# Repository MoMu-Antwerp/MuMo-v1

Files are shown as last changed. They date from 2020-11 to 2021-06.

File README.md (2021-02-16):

# MuMo
The MuMo project is an attempt to make an open source easy to setup platform to monitor environmental conditions of multiple sensors using IOT Lora modules and off the shelf hardware. 

MuMo stands for 'Museum Monitoring' and refers to the initial founder and prototype developer of the project, which is the fashion museum in Antwerp (named MoMu). MuMo is developed in collaboration with the University of Antwerp - Department of Product Development. 

The project consists of 3 main parts. A sensor node design, a gateway that also houses various sensors and a dashboard to visualize all recorded measurements and to alert users of any out of bound values. 

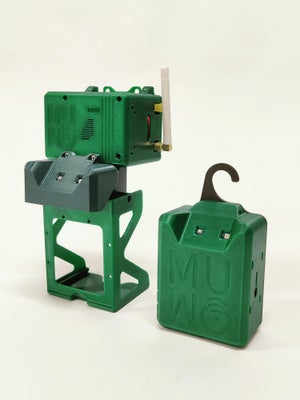
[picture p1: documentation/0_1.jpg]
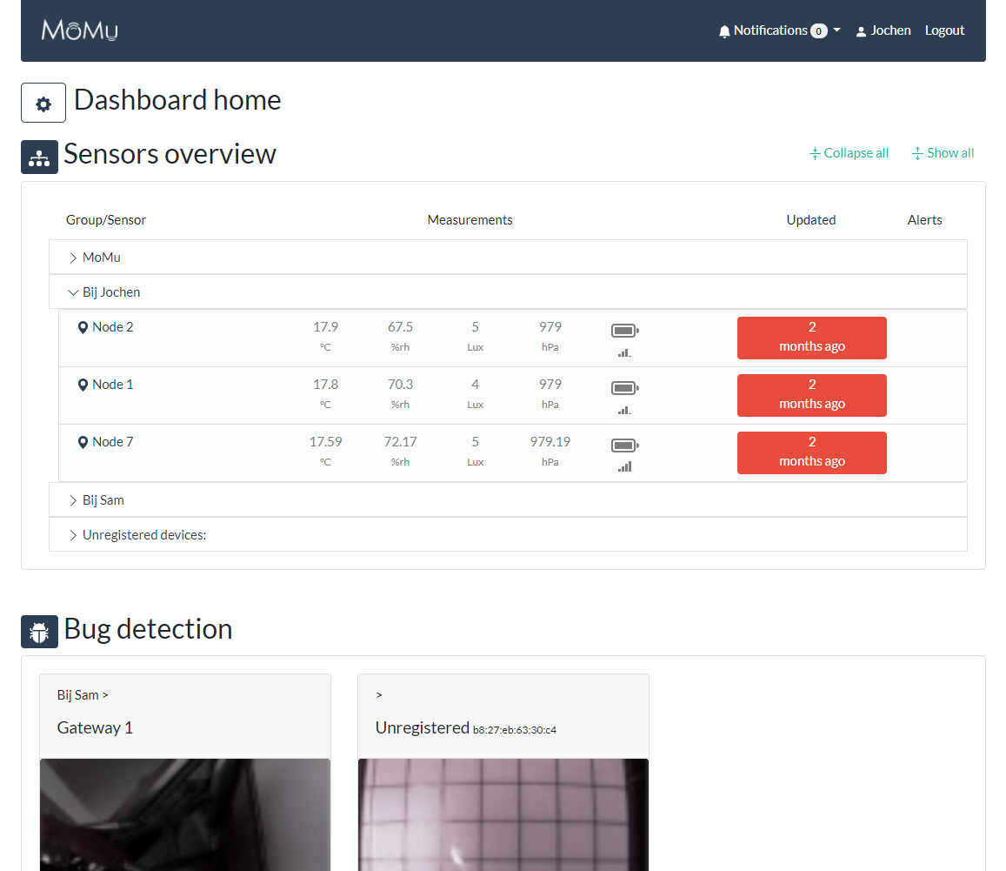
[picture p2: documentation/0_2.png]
 

### The sensor node 

The sensor node is built around a Lorawan Seeed board that contains a ATSAMD21 processor (arduino zero compatible) and a RHF76 Lora module. 

It features Seeed grove sensor connectors that can accommodate a series of sensors. In this project we chose a BME680 that records environment temperature, relative humidity and barometric pressure and a TSL2561 to measure visible light values (in lux). 

To power the unit for a long period of time, we use 6 rechargeable AA batteries that should give the node an operating cycle of around two years (depending on the frequency of measurements sent). 

All in a 3D printer optimized housing and programmable without special tools. 

The code features: 

- The Things Network connection 
- Measurement frequency from minutes to days 
- Intermittent measurements every minute to check for extreme conditions. 
- Immediate warning transmissions if any warnings are raised. 
- Down-linkable updates to all settings 
- Ability to connect other sensors by adding their library and implementation. 
- Decent power efficiency by using the internal RTC of the ATSAMD21 (down to 65 µA) 

### The Gateway 

Build around a Raspberry Pi and containing a Dragino lora concentrator, dust particle sensor, Grove sensor shield with environmental sensors connected and a bug detection camera. Most of these components are modular and optional, so that any useful combination of elements can be made. 

The inclusion of the Dragino Lora concentrator makes this unit a Lora gateway that receives all data from the nodes and forwards the data to the things network through a WIFI connection or Ethernet. Using this board hundreds of nodes can be connected. 

Python code on the Pi records all measurements like is done on the Nodes themselves. But in this case also utilizes the power consuming VOC measurements of the BME680 and an extra dust particle sensor (also power consuming that would not be desirable in the battery powered nodes). 

A night vision camera can be placed in various locations around the unit to record bug traps. It provides a daily updated picture that can give a history log of events that occurred.  

This unit also features a 3D printer optimized housing and is programmable without specialist tools. 

#### Ready made alternative Gateway (TTN indoor gateway)
If you are just interested in the functionalities of the sensor nodes and dashboard, there is an easier alternative Gateway solution. You can order a The Things Indoor Gateway and activate this ready-made gateway in less that 5 minutes. You can find more information [on the site of TTN](https://www.thethingsnetwork.org/docs/gateways/thethingsindoor/index.html).

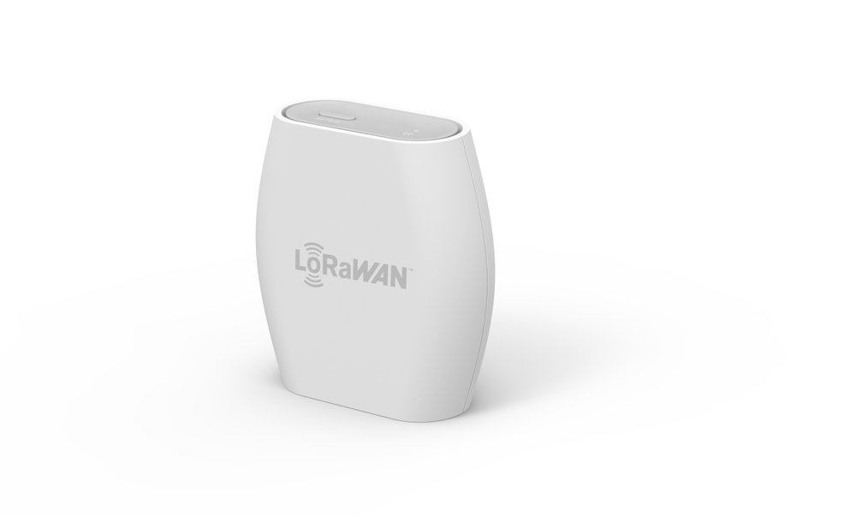
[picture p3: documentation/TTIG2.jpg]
 

### The Dashboard 

The dashboard visualizes the data received by The Things Network. It shows the latest measurements captured by the sensors from the nodes and gateway in one application. And shows graph of all recorded measurements up to date. It gives a manageable overview to setup alerts for any out of bound recordings and can be integrated in other platforms (if desired). On top of this, the calibration of the sensors and user access is managed with this dashboard. 

Requirements: 

- PHP version 5.6 or greater. 
- MYSQL version 5.6 or greater or MariaDB version 10.1 or greater. 
- Online accessible url (may be a subdomain as well) 

## Open source 

All the development done for this project is open to be used, modified and shared if credits are given.  

In this github you can find:  
- Shopping lists for all parts that we used. 
- .Stl files to print any of the housings. 
- Codes for the nodes, gateways and dashboard. 
- Manuals to take you through the assembly step by step. 

# Where to find all parts:
- [Shopping list for the project.](/Shopping_list.md)
---
### Node
- [Step by step assembly manual of the Node.](/Node/readme.md)
- [STL files to 3D print the Node housing.](/Node/STL_NODE)
- [Latest Arduino code of the Node.](/Node/mumoV1)
---
### Gateway / extensions
- [Step by step assembly manual of the Gateway.](/Gateway/readme.md)
- [STL files to 3D print the Gateway housing / extensions.](/Gateway/STL_GATEWAY)
---
### Dashboard
- [Step by step installation of the online dashboard.](/Dashboard/readme.md)
- [All required files can be found in the same folder.](/Dashboard)

# Contributions

The MuMo project is a collaboration between [MoMu](https://www.momu.be/en/) and the [University of Antwerp](https://www.uantwerpen.be/nl/studeren/aanbod/alle-opleidingen/productontwikkeling-studeren/) - [Antwerp design factory](https://www.uantwerpen.be/nl/projecten/mondmaskers/over-ons/antwerp-design-factory/).

Funded by the Flemish Government [Innovatief  partnerproject](https://www.vlaanderen.be/cjm/nl/cultuur/cultuur-en-economie/innovatieve-partnerprojecten) under the name: Developing a IOT Datalogger for Museums using LoRaWan

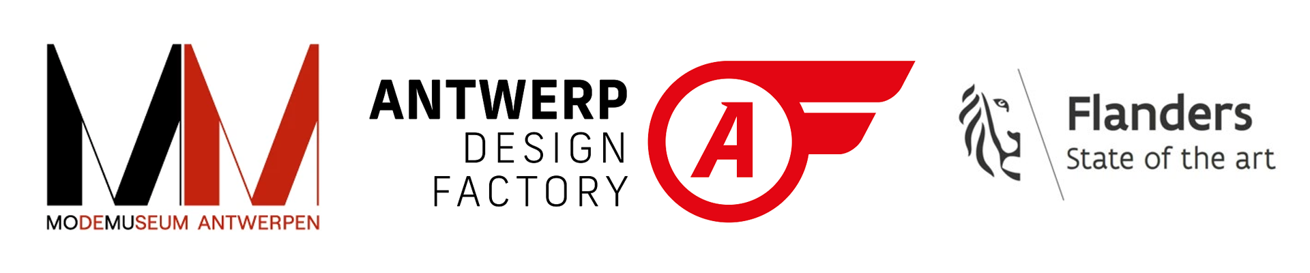
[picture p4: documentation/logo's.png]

---

Shield: [][cc-by-sa]

This work is licensed under a
[Creative Commons Attribution-ShareAlike 4.0 International License][cc-by-sa].

[][cc-by-sa]

[cc-by-sa]: http://creativecommons.org/licenses/by-sa/4.0/
[cc-by-sa-image]: https://licensebuttons.net/l/by-sa/4.0/88x31.png
[cc-by-sa-shield]: https://img.shields.io/badge/License-CC%20BY--SA%204.0-lightgrey.svg

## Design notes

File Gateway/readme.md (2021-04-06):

# MuMo Gateway setup
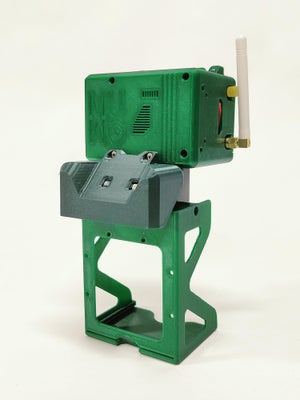
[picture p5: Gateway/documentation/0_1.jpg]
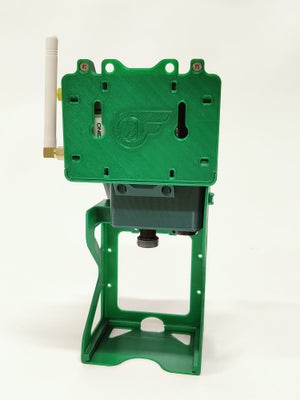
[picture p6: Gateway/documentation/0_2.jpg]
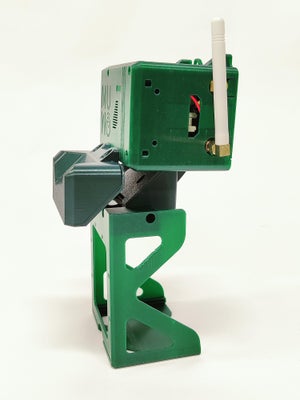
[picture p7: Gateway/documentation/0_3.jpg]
   

### Required Tools:
- 3D printer with filament
- Solder iron / solder
- Small cutting plier
- Hot glue gun (or other fixation tools)
- Small screwdriver

## Step 1: #Hardware - Ordering Parts
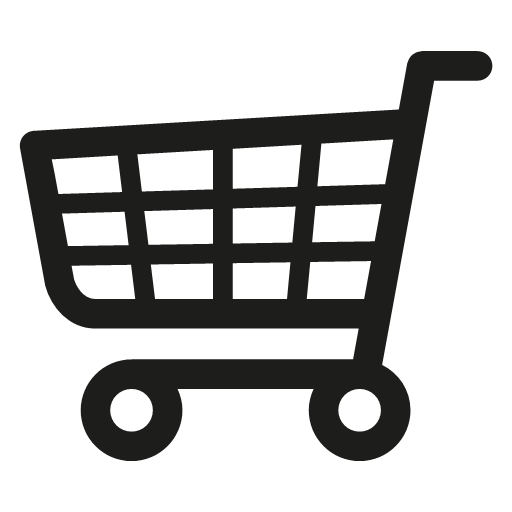
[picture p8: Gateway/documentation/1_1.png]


See the shopping list an up-to-date overview:
- [Shopping list for the project.](/Shopping_list.md)

In the construction of the gateway you have a few options in the features you like to add:
- Either an active or passive gateway (with or without sensors on the gateway).
- Lora gateway or just an active sensor (with or without lorawan concentrator shield).
- With or without camera module for bug tracking or other camera applications.

> In the instructions below we describe the most commong optional parts (without camera and without sensors). 
> But note that you can easily leave out the lorawan concentrator as well if you already have gateways on site.

***Be carefull*** about the screws nearby the Raspberry Pi. Don't overtighten the screws and if you notice it being to close to the electronics we advice you to shim the parts a bit or to use a smaller screw.

## Step 2: #Hardware - 3D Printed Parts
Check the github page for the latest STL files:
[Gateway STL files](/Gateway/STL_GATEWAY)
- ***1x*** GATEWAY_Main_Housing
- ***1x*** GATEWAY_Backcover
- ***1x*** Sensor_extension
- ***1x*** Sensor_Housing
- ***1x*** Sensor_Backcover
- ***1x*** Camera_Housing
- ***1x*** Camera_Backcover

### Material and print settings:
- ***PETG*** preffered (for durability against the heat of the gateway)
- No supports needed
- Infill not necessary
- 0.2 layer height
- 3 outside perimeters (for strength and durability)

## Step 3: #Software - Prepare SD Card Raspberry Pi
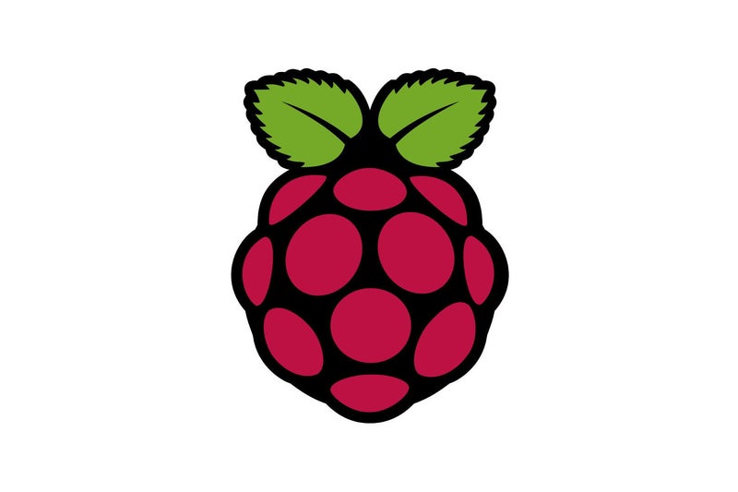
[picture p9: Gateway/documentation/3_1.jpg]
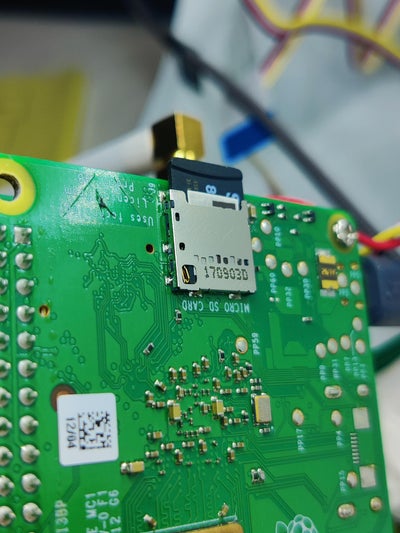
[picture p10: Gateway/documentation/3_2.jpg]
 

### Parts:

- ***1x*** Raspberry Pi
- ***1x*** Micro SD card.

### Instructions:

1. Make sure the SD card is flashed with the Raspberry Pi operation system (Raspberry Pi OS(32-bit) with desktop). 
1. Insert your micro SD card into the Raspberry Pi.

> Follow the link below to find more detailed instructions how to flash and prepare your micro SD card. [Raspberry installation instructions](https://www.raspberrypi.org/documentation/installation/installing-images/)

## Step 4: #Hardware - Prepare the Air Dust Sensor (optional)

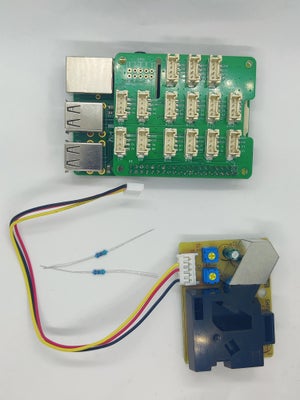
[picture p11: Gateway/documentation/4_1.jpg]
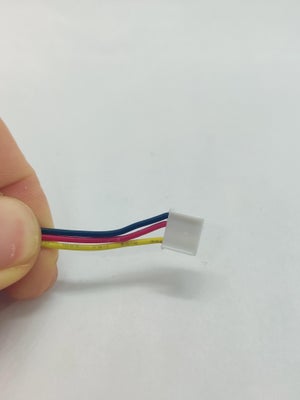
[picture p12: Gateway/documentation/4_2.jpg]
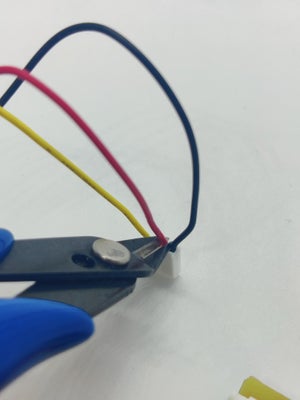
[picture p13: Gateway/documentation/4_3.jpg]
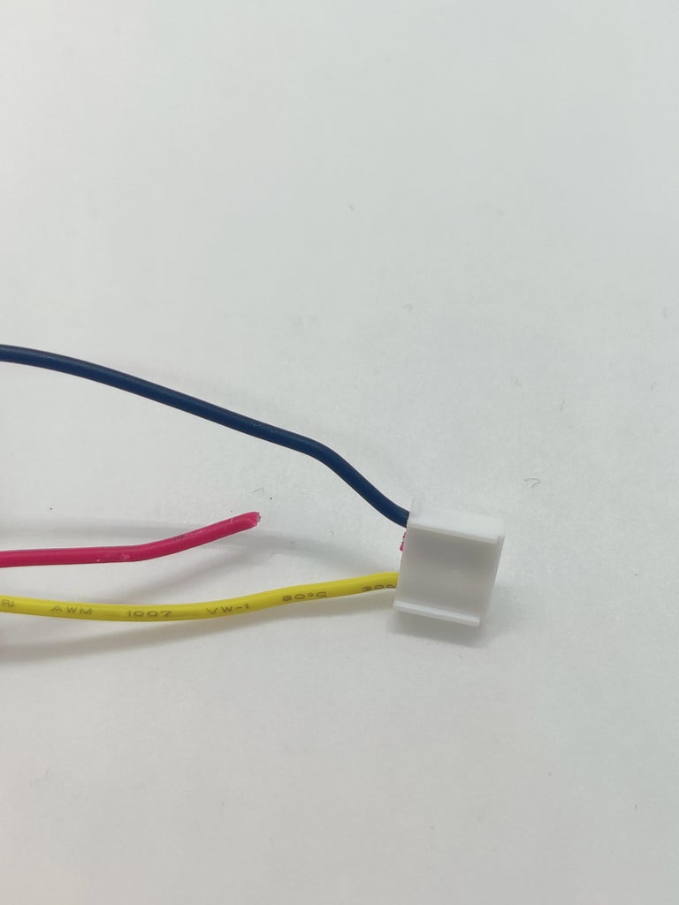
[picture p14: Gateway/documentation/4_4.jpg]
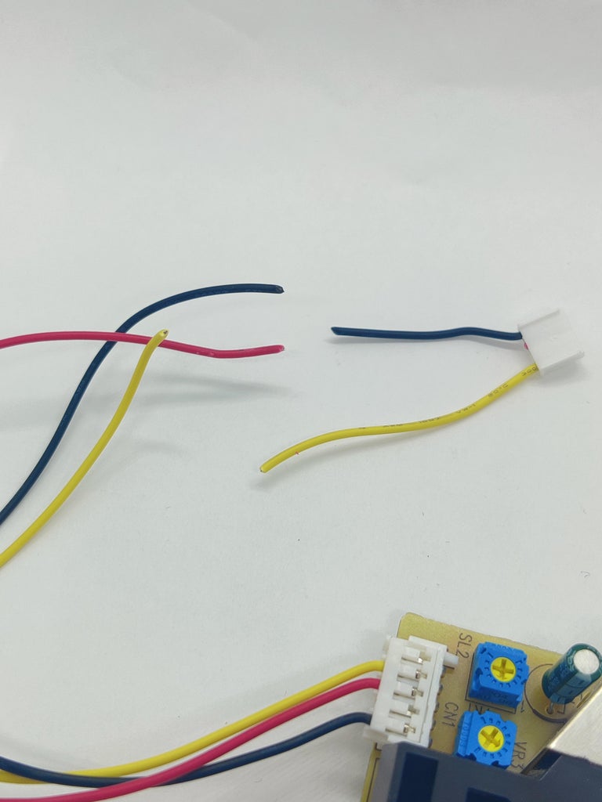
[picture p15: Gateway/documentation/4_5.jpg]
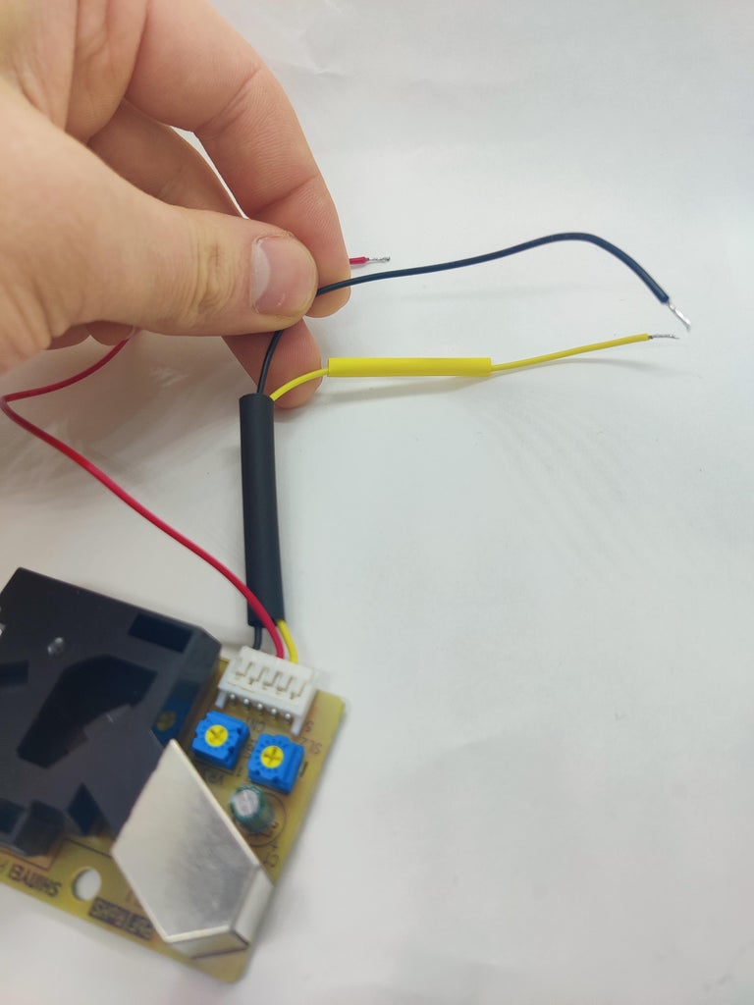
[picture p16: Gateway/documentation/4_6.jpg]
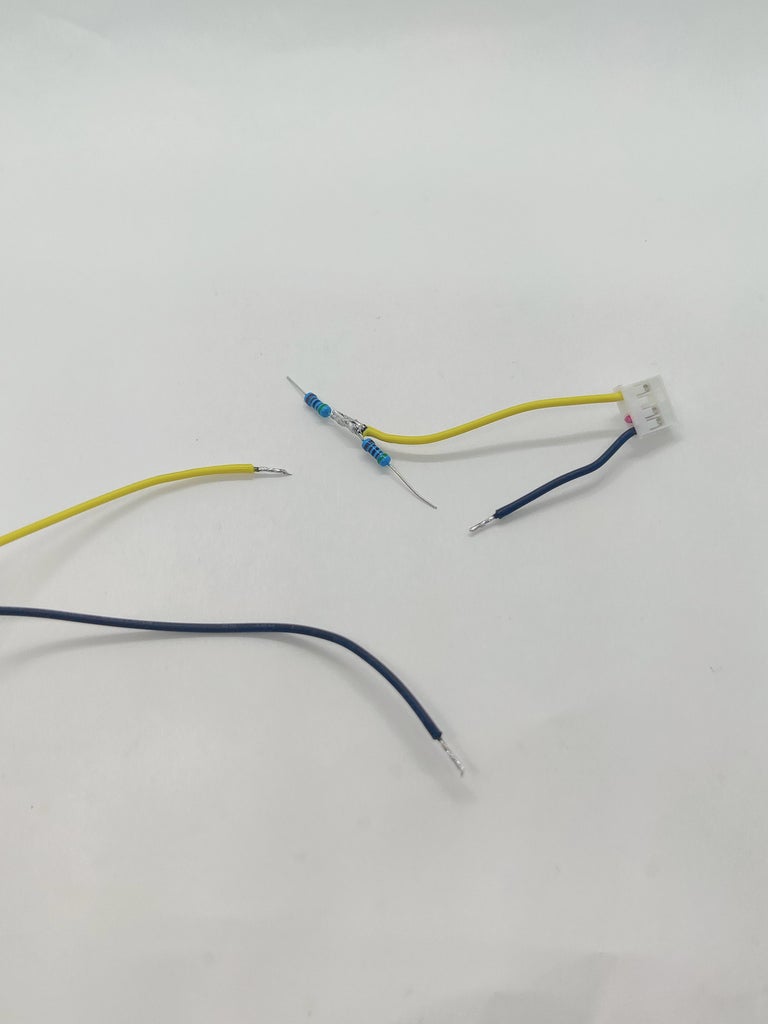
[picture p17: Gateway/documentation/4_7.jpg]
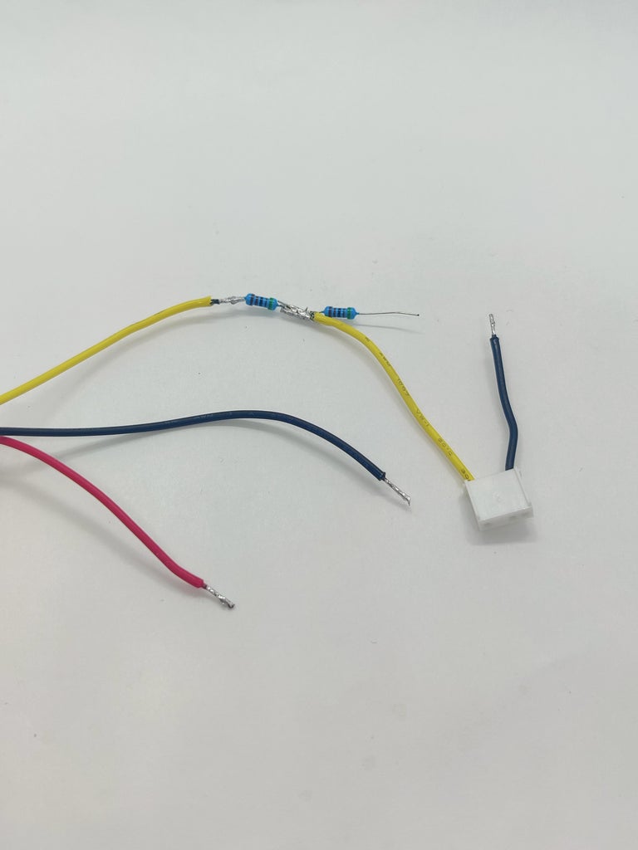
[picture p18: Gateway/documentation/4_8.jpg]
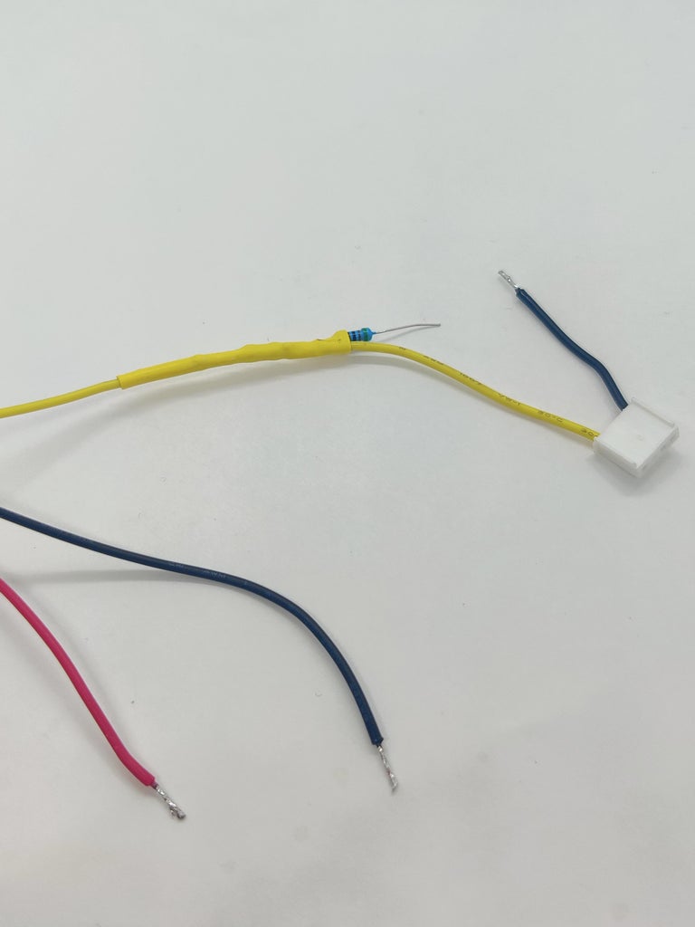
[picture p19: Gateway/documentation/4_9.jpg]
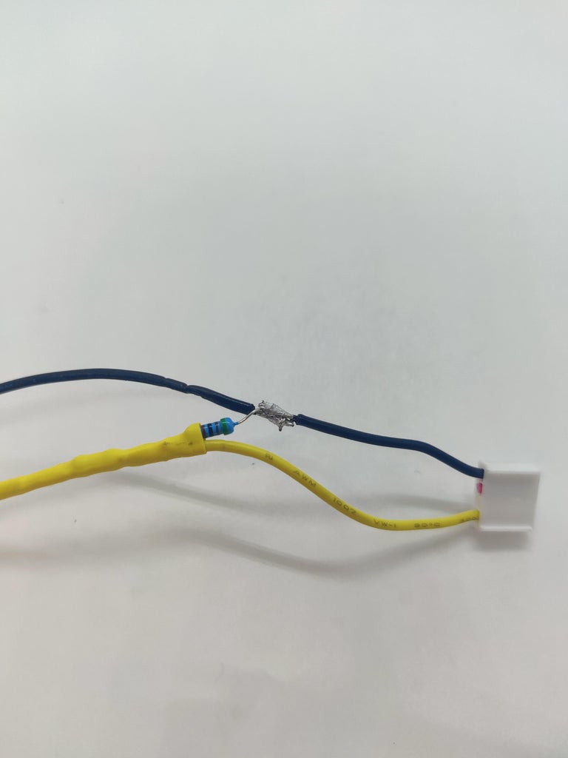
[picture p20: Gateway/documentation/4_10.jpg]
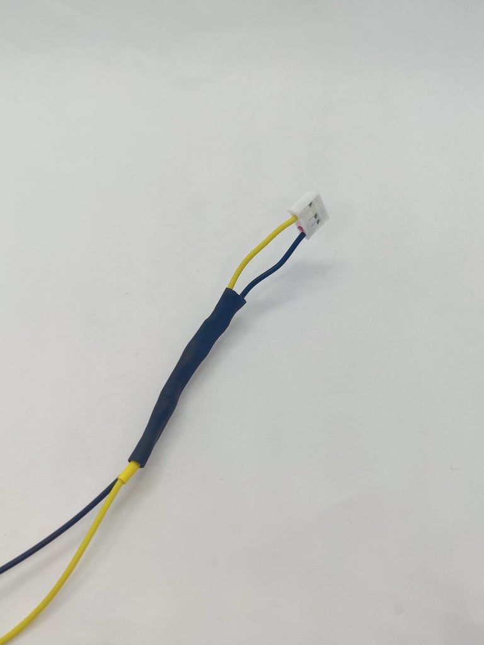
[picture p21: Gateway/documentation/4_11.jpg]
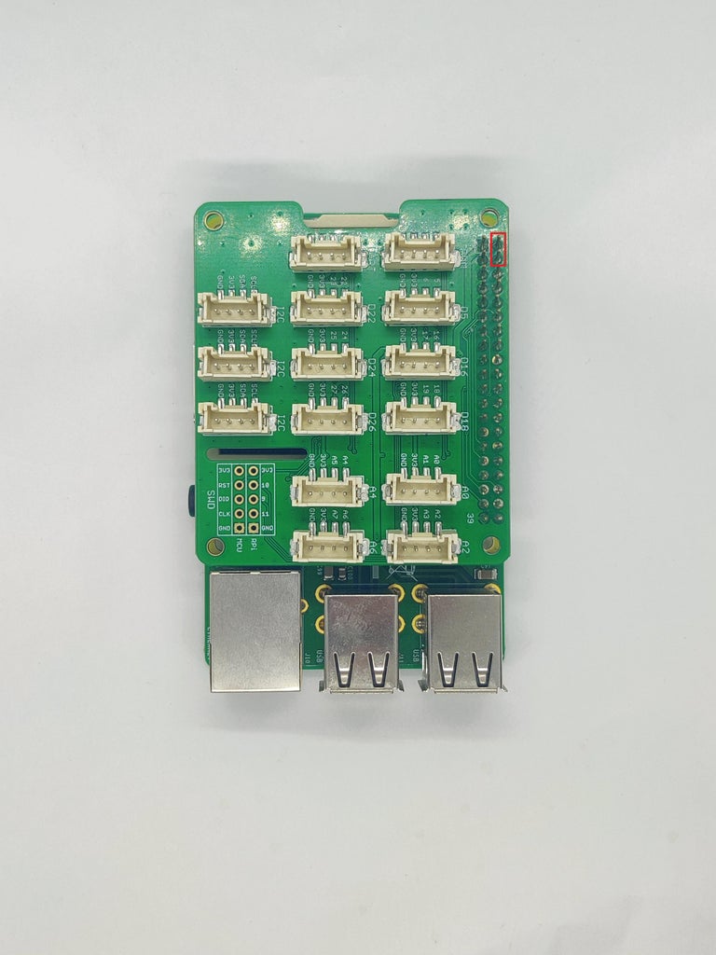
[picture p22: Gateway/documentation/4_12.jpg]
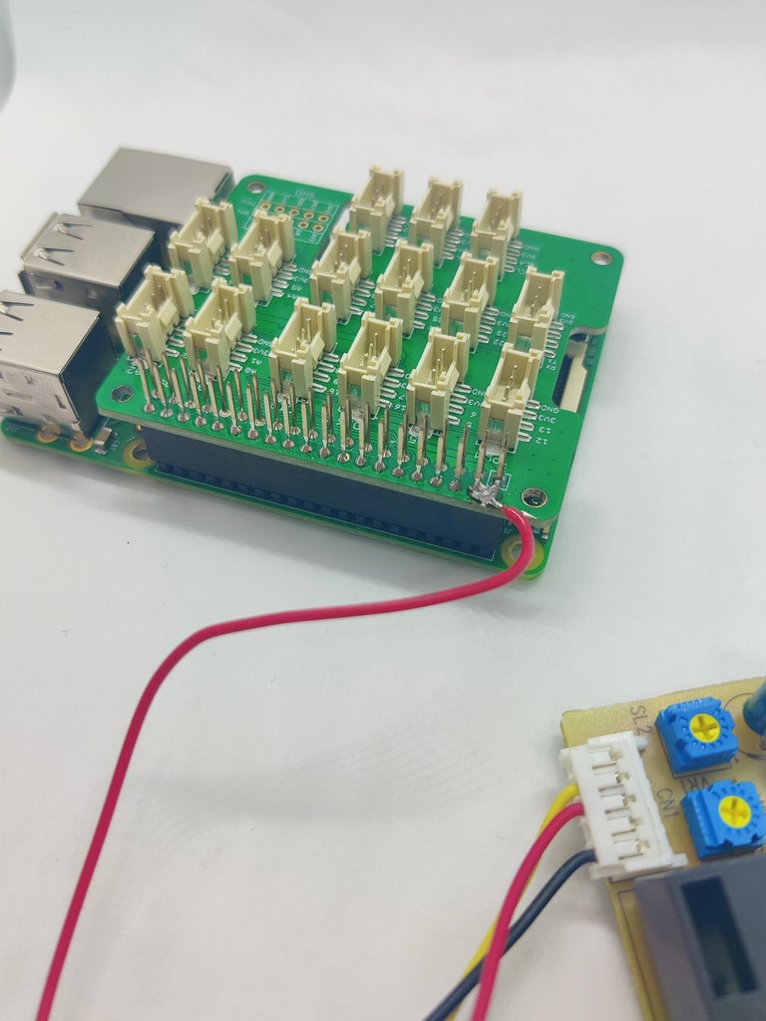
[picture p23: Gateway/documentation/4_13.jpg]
             

Since the air dust sensor works on 5V supply and the raspberry pi only works on 3.3V we need to include a voltage devider in the cable using two resistors.

### Parts:

- ***1x*** Seeed air dust sensor
- ***2x*** resistor (3.3 KΩ) (orange, orange, red)
- ***1x*** Grove hat
- ***2x*** shrink sleeves

### Instructions:
1. Cut the red wire up to the connector.
1. Cut the yellow wire at a distance of 3 cm from the connector.
1. Cut the black wire at a distance of 2 cm from the connector.
1. Strip the end of each wire.
1. Put a small shrink sleeve over the yellow cable.
1. Put a large shrink sleeve over the yellow and black cable.
1. Solder the two resistors in series with the yellow cable of the connector in between.
1. Solder the other yellow cable on the side of the sensor to one of the resistors.
1. Slide the small sleeve over the solder connection of the yellow wire with one resistor end still exposed and heat shrink the small sleeve.
1. Solder the black wires back together with the still exposed resistor leads in between.
1. Slide the large sleeve over the solder connection and the small sleeve and heat shrink the large sleeve.
1. Solder the red cable to the 5V pins (pin 2 and 4) on the Grove hat board (see the top view picture).

## Step 5: #Hardware - Mounting the Spacers (optional)
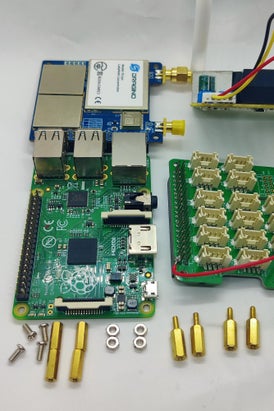
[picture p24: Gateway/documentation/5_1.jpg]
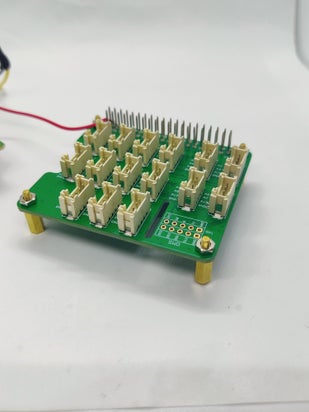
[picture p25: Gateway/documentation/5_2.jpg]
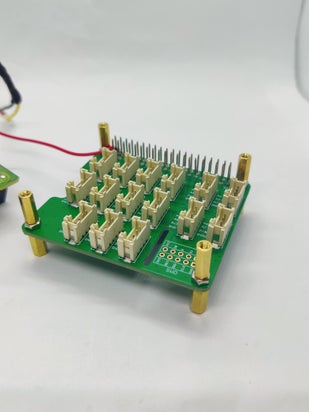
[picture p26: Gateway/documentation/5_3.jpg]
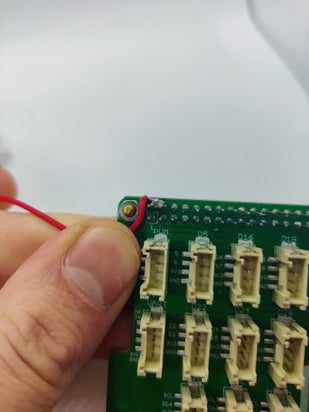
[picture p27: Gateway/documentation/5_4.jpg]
   

### Parts:

- ***1x*** Grove hat board
- ***1x*** Seeed air dust sensor
- ***4x*** female-male spacers
- ***4x*** female-female spacers
- ***4x*** nut

### Instructions:
1. Mount the female-male spacers through the mounting holes of the grove hat board
1. Screw the nuts on the female-male spacers and tighten it. (to provide extra space for the cables to bend)
1. Screw the female-female spacers on top of the nuts and tighten everything.
1. Lay the red 5V cable of the airdust sensor along the inside of the spacer (see last picture).

## Step 6: #Hardware - Connecting Camera Cable / Dust Sensor / I2C (optional)
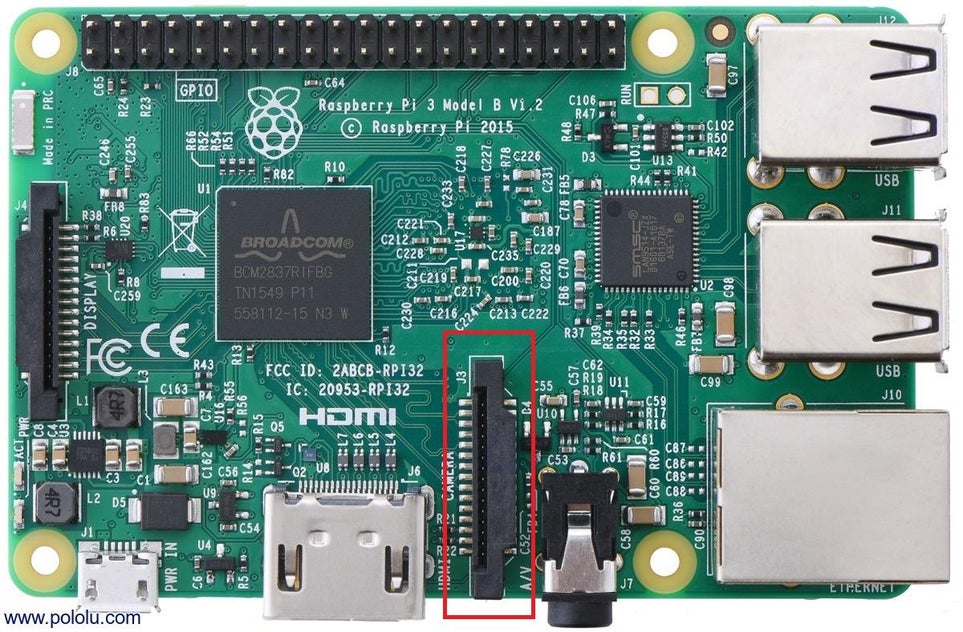
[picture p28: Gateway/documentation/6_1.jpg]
           

### Parts:

- ***>*** The assembly stack from step 6
- ***1x*** Raspberry PiModel 3 B+
- ***1x*** Camera cable
- ***2x*** grove connection cables
- ***1x*** Long M2.5 screw from the Grove hat bag

### Instructions:

__Camera cable:__
1. Lift the latch of the cable connecter on the Raspberry Pi (see picture one - red rectangle). Be careful, fragile!
1. Insert the camera cable in the connector of the Raspberry Pi with the blue side facing the usb plugs.
1. When the cable is in the right place. Push the latch back into place so the cable connection is secured.
1. Feed the camera cable trough the provided hole into the grove board. (see picture of the grove board top view - red rectangle)
1. Align the board with the pin connections on the side.
1. Push it al the way down to make a stack.
1. To secure the stack, mount the screw in the hole next to the audio connection of the raspberry pi. (see picture top view)
1. The first stack is complete!

__Air dust sensor:__
1. Connect the connector of the air dust sensor to pin D16 of the Grove hat board. ( see picture of the grove board top view - purple rectangle )

__I2C connectors:__
1. Connect the two grove connection cables to the I2C connectors of the the Grove hat board. Preferably use the connectors that are close to the camera cable. This makes it easier to use the HDMI port afterwards. ( see picture of the grove board top view - blue rectangle )

## Step 7: #Hardware - Building the Stack Into the Housing
      

### Parts:

- ***>*** The assembly stack from step 6
- ***1x*** Gateway_body 3D print
- ***1x*** M3 x 12
- ***3x*** Long M2.5 screws from the Grove hat bag

### Instructions:

1. Check if the micro SD card is inserted into the Raspberry Pi.
1. Insert the air dust sensor in the 3D print housing and secure it with the M3 screw.
1. Before we insert the stack. Guide the camera cable and the two I2C grove connection cables through the bottom slot in the housing.
1. Insert the Pi stack into the housing.
1. Push the cables down on the side so they don't get in the way.
1. Make sure that no wires are in front of the Micro USB and the HDMI connection.
1. Secure the stack with three M2.5 screws through the big holes in the front.

## Step 8: #Hardware - Dragino LoRa Shield
  

### Parts:

- ***>*** The assembly from step 7
- ***1x*** Dragino LoRa shield
- ***4x*** Short M2.5 screws from the Lora Concentrator bag

### Instructions:

1. Pre install the antenna to the Dragino LoRa shield. (don't fully tighten yet!)
1. Insert the Dragino LoRa shield on top of the grove hat board. Align the pins and push it all the way down.
1. Secure the board with the four M2.5 screws.

## Step 9: #Hardware - Backcover
   

### Parts:

- ***>*** The assembly from step 8
- ***1x*** Gateway_backcover
- ***2x*** M3 x 12 screws

### Instructions:

1. Slide the inserts of the backcover into the housing and push it down.
1. Fixated the backcover with two M3 screws.

## Step 10: #Hardware - Setup LoRa Gatway


### Parts:

- ***>*** The assembly from step 9
- ***1x*** Peripherals: screen (HDMI) / keyboard / mouse
- ***1x*** Micro usb power supply (5.1V 2.5A)
### Instructions:

1. Connect the Raspberry to a screen with a HDMI cable.
1. Connect a mouse, keyboard to the USB connector.
1. Plug in the power usb cable to the Raspberry Pi last. 
    - It should start booting up now.
    
In these instructions we chose to use a display connected at all times during setup. You can also choose to connect trough SSH, but then you do not get to see all the visual information that often helps you along the way. 

## Step 11: #Software - Setup LoRa Gatway - First Start Up Raspberry Pi
        

### Instructions:

1. You will see the setup screen. Follow the setup screen instructions.
1. Choose your county / network / keyboard setting
1. At the end it will search for updates and install them.
    - Please be patient, this can take a few minutes.

## Step 12: #Software - Setup LoRa Gatway - Get Ether Adress for TTN


### Instructions:

1. Open a terminal on the Raspberry Pi.
1. Type in > `ifconfig wlan0:`
1. You can see the ether address of the Pi. (ex: b5:23:eb:fc:55:d4)
1. ***Write this down*** because you will need it when setting up the gateway in TTN.

> For more detail setup information about the Dragino PG1301, check their user manual (page 7): [Dragino PG1301 user manual](http://www.dragino.com/downloads/downloads/LoRa_Gateway/PG1301/PG1301_UserManual_v1.0.2.pdf)

## Step 13: #TTN - Sign Up / Log in


The things network provide a set of open tools and a global, open network to build your next IoT application at low cost, featuring maximum security and ready to scale.
[https://www.thethingsnetwork.org/](https://www.thethingsnetwork.org/)
> If you already have an account you can skip this step.

### Instructions:

1. Sign up at The Things Network and make an account
1. Follow the instruction on the TTN website.
1. After Sign up log in to your account
1. Go to your console. You will find it in the dropdown menu of your profile (see picture)

## Step 14: #TTN - Create a Gatway on the TTN
  

### Instructions:

1. In the console on TTN, click on Gateway.
1. Click on register gateway in the upper right corner to at a new gateway device. (see picture - red square)
1. Check the box of "I'm using the legacy packet forwarder". (see picture - green square)
1. Fill in the gateway EUI by using the ether address from the Pi. Convert your address like this example `b5:23:eb:fc:55:d4` => `B523EBFC55D4FFFF` (see picture - green rectangle) The "FFFF" gets added to make it a 8 byte unique EUI.
1. Choose your Frequency plan ( ex: Europe - 868MHz for Europe)
1. Choose your router ( ex: ttn-router-eu for Europe)
1. Point your location on the map. (optional)
1. Check the right box, indoor or outdoor.
1. On the bottom of the page click on the button Register Gateway

## Step 15: #Software - Setup LoRa Gatway - Interface Options
  

### Instructions:

In the terminal type in > `sudo raspi-config`
- Select Interface options
    - Select and enable SPI
    - Select and enable Camera
    - Select and enable I2C

## Step 16: #Software - Setup LoRa Gatway - Download and Install LoRaWAN Packet Forwarder Enable SPI
 

### Instructions:

1. In the terminal type in > 
`wget http://www.dragino.com/downloads/downloads/LoRa_Gateway/PG1301/software/lorapktfwd.deb`
1. This will download the packet forwarder from Dragino Server to RPI.
1. In the terminal type in > `sudo dpkg -i lorapktfwd.deb`

## Step 17: #Software - Setup LoRa Gatway - Config Gateway ID, Frequency Band and Server Address
 

### Instructions:

1. After installation, go to `/etc/lora-gateway/` and open local_conf.json
1. In between the curly brackets add this section below:
    ```
    "gateway_ID": "B523EBFC55D4FFFF",
    "server_address": "router.eu.thethings.network",
    "serv_port_up": 1700,
    "serv_port_down": 1700
    ```
    - Make sure to place the correct structure with , after each line and no , at the last line. 
    - " " around all text values and none around the numbers.
1. Change the gateway_ID to the gateway_ID you used to setup the gateway in the TTN. (with the "FFFF")
1. Save the document.

## Step 18: #Software - Setup LoRa Gatway - Start the LoRa Network
 

### Instructions:

1. In the terminal type >
    ```
    sudo systemctl stop lorapktfwd
    sudo systemctl start lorapktfwd
    sudo systemctl enable lorapktfwd
    ```
1. This restarts the package forwarder and makes sure the forwarder starts with Raspberry Pi. 
    - Now your LoRa gateway is active.
1. You should see the status update to "connected" within a few minutes on TTN.

## Step 19: #Software - Setup Gateway - Sensor / Camera - Install (optional)
     

### Instructions:

1. Check if you have python 3 on your Raspberry Pi. In the terminal type => python3
1. If you don't have python 3, follow this install instructions:
1. type => `sudo apt update`
1. type => `sudo apt upgrade`
1. type => `sudo apt install python3 idle3`
1. Now you should have python 3. Please check again with the 1. first step.
1. Activate camera / I2C / SPI: _(you might have done this already in the LoRa setup)_
1. In the terminal type => `sudo raspi-config`
    - Go to Interfacing Options.
        - Enable camera
        - Enable I2C
        - Enable SPI
1. Install following libraries: (type these commands in the terminal)
    ```
    sudo apt-get update
    sudo apt-get upgrade
    sudo apt-get install libatlas-base-dev

    pip3 install numpy
    pip3 install opencv-python
    pip3 install scikit-image
    pip3 install schedule
    pip3 install getmac
    pip3 install adafruit-circuitpython-bme680
    pip3 install adafruit-circuitpython-tsl2561
    pip3 install RPI.GPIO
    ```

## Step 20: #Software - Setup Gateway - Sensor / Camera - Script Run (optional)
  

### Focus setup:
1. Before running the final code we have to focus our camera unit. 
1. In a command line window type:
    ```
    from picamera import PiCamera
    from time import sleep

    camera = PiCamera()

    camera.start_preview()
    sleep(20)
    camera.stop_preview()
    ```
1. This provides you a live preview of the camera. 
1. Focus the camera by rotating it's lens.
1. After 20sec the preview stops, but you can re-run the code as much as needed.

### Instructions:

1. Download the python script `mumo.py` from github: [Gateway python code](Python/mumo.py)
1. Place the code on your desktop.
1. Open a terminal and type > `sudo nano /etc/xdg/lxsession/LXDE-pi/autostart`
1. Copy this line on to the bottom off the file > `@lxterminal -e python3 /home/pi/Desktop/mumo.py`
1. Save the file and close it.
1. Now the script will automatically start at restart.
1. Open the code.
1. ***Change to your URL endpoint.*** 
    - This is where to send the data on your backend server.
    - This data goes straight to the dashboard and not trough TTN.

## Step 21: #Hardware - Sensor Extension (optional)
         

### Parts:

- ***>*** The assembly from step 9
- ***1x*** Sensor_body
- ***1x*** Sensor_cap
- ***1x*** Digital light sensor (small sensor)
- ***1x*** BME680 sensor (long sensor)
- ***4x*** M2 x 5 screws
- ***4x*** M3 x 12 screws
### Instructions:

1. Insert the two I2C grove connection cables through the hole of the sensor_cap.
1. Connect the BME680 sensor and the digital light sensor to the I2C grove connection cable.
1. Insert the BME680 sensor and the digital light sensor into the sensor_body part and secure it with four M2x5 screws. You will have to bend the cable to fit the sensors into place, so be careful!
1. Slide the sensor_cap on top of the sensor body to close it.
1. Fixated the cap to the body with two M3 screws.
1. Attach the sensor add-on assembly to the front of the gateway with two M3 screws. (see picture - Red circle)
1. The grove cables are probably too long. Push them inside the sensor housing.

## Step 22: #Hardware - Camera Extension (optional)
            

### Parts:

- ***>*** The assembly from step 10
- ***1x*** Camera module (with M2.5 screws)
- ***1x*** Camera_body
- ***1x*** Camera_cap
- ***4x*** M3 x 12 screws
### Instructions:

1. Place the camera and one light attachment into the camera_cap housing and secure it with the four M2.5 screws from the camera module.
1. To insert the camera cable we must lift the black plastic holder from the connection.
1. Insert the camera cable with the blue surface facing the camera. (see pictures)
1. Slide the camera_body on top of the assembly
1. Fixated the camera_cap with two M3 screws to the camera_body.
1. Mount the camera add on assembly to the bottom off the gateway housing with two M3 screws (see picture - Red circle)
Push the protruding cable into the housing.

## Step 23: #Hardware - Bug Trap Extension (optional)
          

### Parts:

- ***>*** The assembly from step 11
- ***1x*** Trap_Frame
- ***1x*** bug trap paper - sticky paper
- ***2x*** M3 x 12 screws
### Instructions:

1. Place the Trap_Frame part on top of the camera housing. The trap has some space for the power usb cable of the gateway, therefore check the pictures for the correct orientation.
1. Fixate with two M3 screws on the left and right side of the camera housing.
1. Insert your (60 x 75) mm bug paper into the slot of the trap. There are two slots, in the front and back direction. It depends how you will position the gateway.
1. The power usb cable can be weaved between the open structure of the trap part.

## Step 24: #Hardware - Mounting the Gateway
### The gateway is provided with many options to mount the gateway.
      

We have two screw slots on which the gateway can be hung.

And also have cable ties grooves, so you can easily attach the gateway to anything.

## Step 25: #Hardware - Differed Orientations
The gateway is modular so that the sensors and camera can be mounted in different orientations. You can also create your own components and add them to the setup.

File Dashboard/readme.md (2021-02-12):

# MuMo Dashboard documentation

The MuMo dash is a platform that receives data from nodes trough the things network or via direct post packages from active gateways.  
The dashboard gives you clear overviews of all sensor's measurements and graphs over time.  
All measurements can be constricted so that out of bound measurements can be flagged and reported over mail.   
The primary application for this dashboard is monitoring over IOT sensor networks that monitor environmental conditions in a storage facility that should be kept in climatized conditions. But can be altered to host a bunch of applications.  
Also provided is a daily camera update to keep track of slow visual effects like bug traps, rodent traps, daily workspace log or others.

Please also look at our other pages for details on the custom end-nodes and active gateways. 

## Requirements
* PHP version 5.6 or greater.
* MYSQL version 5.6 or greater or MariaDB version 10.1 or greater.
* Online accessible url (may be a subdomain as well)
> Almost every webhost available online should support this.

## Settings.php
- First of all go to your webhosts settings and create a new MySQL database and user. 
    - This process varies from webhost to webhost. So check your providers documentation for details. As a general guide search for database management and add a database user. 
    - Use a different password then your webhost account please!
    - In the example i create a database called mumo_dashboard.
- Rename the `Edit_me_settings.php` file to `settings.php`. 
    - (the file is named like this so updates can be placed without a chance of overwriting this file).
- Update these settings in the settings.php file of this project `mysqli_connect("localhost","user","password","database");`
- Also update the domain name of your website and the base url. (the domain is used in emails, the base url to create direct links).
    - The url should always start with http:// or even better https:// if your site supports it. 
    - The url should link to the home folder of the website. Not to a specific page or subfolder.
    - It should not have a trailing / or file extension
    >Examples: https://example.be or http://mumo.example.be or https://example.be/mumo
- If you want a different logo or project name, these can also be changed here.
- The bottom of the settings.php file contains a measurements list that contains all types of measurements that can be entered into the dashboard. This tells the dashboard how to call and handle all measurements. You can add all custom measurements to the back of this list. For visual purposes limiting it to 7 measurements per sensor is advised.
- Options:
    - Print_name: Name to be shown in the website
    - Variable_name: How the data is named in the endpoint data from TTN and in the platform and database (no capitals or strange characters)
    - Unit: Unit to be printed after the values
    - Type: Datatype (determines how to present the data)[options: float (2 decimal places), big_float(4 decimal places), int(no decimal places)]
    - Color: Color to use in the charts
    - Calibration: Limiting range in the calibration settings
    - Range: probible range the values will fall within (limits the alert ranges)

## Database setup
- Then we need to setup our database. Therefore, go to the phpMyAdmin page of your domain (often also to be found in your webhosts portal as phpMyAdmin or database access). Open the database you just created on the left (e.g.: mumo_dashboard). 

- Go to import with the button on top, upload the database.sql file from the root of the project and click Go. This will install all tables needed for the project. In case of errors popping up, please open a bug report here on GitHub so we can help.
- The final thing to alter is to make sure you have an account to login to on the dashboard. Open the users database and edit the email address of the admin user. You can also change the users name and login now if you prefer.   
(the name is what is shown in the dashboard, the login is what you prefer to login with).
 
The password will be edited later, so leave this for now. This is a hashed and encrypted representation. So if you edit here you will not be able to login with that password. If you did edit already, here is the hash to overwrite it again: 
```$2y$10$rL5CX0JADSAH2ZyeFlpj1OWgm4q/m20Ta.fjTA9wj456q8NsXtof2```

## Deploy
- Deploy all files of this project to your webhost. This is normally in the public_html folder.
- Go to your url and you should get a login page without any errors above. Again, if you see any errors, please report them in the bug report section on GitHub.
- Login using either the stock admin user or your custom entry and use the password "password"
![alt text](documentation/login.png) 
- You should now be logged in and see the home of the dashboard.

## How the platform works

### Dashboard
- On the dashboard you get an overview of your sensors last measurements as well as battery level and signal strength.
- On the bottom also the bug traps latest image is shown. 

### Global Settings
- In the left top (next to Dashboard home now) will always be a settings button. Depending on the page you are on this might be global settings or settings for the opened device. Please open these settings now.
- You see here sections of settings like 'user accounts', 'groups and devices' and 'global hardware alerts'.
- Check the site endpoint url. If it shows any alerts you must check back in the settings.php file for the base $url. See the list of instructions in the settings.php section up above. 

    ## Setting up the ***endpoint*** in TTN
    - A small deviation from the explication of the functions of the settings is the Endpoint url that has to be registered with TTN (the things network) in order to receive data from your sensors.
    - Go to [thethingnetwork.org](https://www.thethingsnetwork.org/) and login to your account.
    - In your application that you would like to connect open the ***integrations*** tab.
    - Click `add integration` and choose for an `HTTP integration`.
    - Give your process a unique ID of you own liking and select the default acces key.
    - Enter the endpoint url as found in the dashboard settings.
    - Leave the rest of the settings as stock with method being Post and the rest of the options empty.
    - Click `Add integration` and all should be fine. 

    ![endpoint.png](documentation/endpoint.png)

    - If you have an active endpoint: these will start showing up in the dashboard as soon as they transmit data. 
    - If you don't receive any data from your sensors. Open the endpoint URL yourself in the browser. You should receive a message saying: `Mumo: endpoint is active.`. If not, check your server setup and url for any errors.

    - This endpoint URL is also used in our custom active gateways python code. They transmit their readings directly to the dashboard without TTN.

#### Users
- In user accounts you can invite new users by adding their email address and screen name. They will receive an invite to choose their login name and password (please do tell them to check their spam folder).
- Here you can also change your account and you should certainly change your password. Using the send reset link by email.
- Users are grouped in 2 types. With or without editing rights. Users without editing rights see the exact same page as you do. But the settings button on the top left of every page is just an icon for them.

#### Groups and devices
- For now no groups or devices will be present. You can already start adding your group structure for your application now.   
Groups can be nested as much as you want. But visually we advise to keep it limited.
- To add devices, the dashboard just needs to receive some data input from them. They will show up as unregistered as soon as their first transmission is received. It is easier to place them into groups later (otherwise you would have to register them using long identification numbers).

#### Global hardware alerts
- These values count as the boundaries wherein data may be received. If any data received falls without these bounds it will trigger a warning and email.
- The alerts are split in local (sensor) alerts and global alerts. This means that every sensor without modification will follow the global alerts. Only if the local sensor alert is set it overrules these global set values.
- Alerts are also split in hardware and sensor alerts. For example, the battery level and signal quality can be forwarded to a manager in the building. Whereas the sensor values can be sent to the maintainers of a specific collection.
- Check the checkbox in front of the line to activate the alert. Or uncheck the box to remove the alert again.
- As a safety precaution only users that have completed their registration are accepted to receive alerts. So, we are sure they cleared the emails from being marked as spam.

Emails will be sent as soon as a sensor goes out of bound on one of these triggers. A closing email will be sent when the trigger is cleared and thus the values are again within bounds. Or, if the alert lasts more than a day it will repeat the email daily until resolved.

### Sensor settings
- If you open a sensor before clicking the settings button you will enter the sensor settings.

### Information
- Here you can alter the name, location and note of the sensor.
- If you provide a url this will be shown as a link icon after the name of this sensor. This can be used to link to its location or collection details.

### Calibration
- You can provide offsets that need to be corrected on the measurements from the device. Please note this will impact the future measurements but it will not update past measurements.

### Iframe pages
- These links can be used to place information from a sensor in a different webpage. If you want to place up to date information you can place these wherever you want. These will be visible for anyone who wants (so are not limited to registered users).
- Options will follow to adjust what will be shown and what the overview will look like.

### Local alerts
- On top of the alerts section it will show whether the settings are the global ones or have been overruled by local settings. They work exactly the same as the global ones. But this way you can make exceptions in whatever way you want to the global ones.

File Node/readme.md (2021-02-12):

# MuMo Node setup
      

### Required Tools:

- 3D printer with filament
- Solder iron / solder
- Small cutting plier
- Hot glue gun (or other fixation tools)
- Small screwdriver

## Step 1: #Hardware - Ordering Parts


See the shopping list an up-to-date overview:
- [Shopping list for the project.](/Shopping_list.md)

## Step 2: #Hardware - 3D Printed Parts
   

Check the github page for the latest STL files: [Node STL files](/Node/STL_NODE)

- ***1x*** NODE_Main_Housing
- ***1x*** NODE_Battery_Tray
- ***1x*** NODE_Backcover

### Print settings:
- PETG (preferred and more durable), but PLA also works.
- No support needed
- Infill not necessary
- 0.2 layer height
- 3 outside perimeters (for strength and durability)

## Step 3: #Hardware - Prepare the Battery Tray
   

### Parts:

- ***2x*** battery case (Side node: You can also use just one battery case for 3 AA batteries but the live range will be shorter!)
- ***1x*** JST 2.0 power connector (included with the Seeed LoRaWan board)
- ***1x*** 3D printed part: battery tray

### Instructions - Soldering: (Warning HOT - be careful!)

1. Solder all the red cables together
1. Solder all the black cables together.
1. Make sure that the soldering work is protected with insulation material. 
    - This can be a sleeve that you pull over the cable before soldering or insulation tape that you apply afterwards.

### Instructions - Fixation of the battery holder:

1. Glue the battery holders into the battery tray so that the cables are facing to the side with the cutout (see picture). 
    - This can be done with hot glue (preferred), double sided tape, silicone, second glue,...

## Step 4: #Hardware - Prepare LoRaWan Board
    

### Parts:

- ***1x*** LoRaWan board

### Instructions:

1. Before removing the led on the board, connect the board to the computer and check if the power led light up. After removing the led we have no power indication anymore.
1. In order to reduce the power consumption of the Lorawan shield we should remove two LEDs that are purely informative. The power (PWR) and the charge indication (CHG) led.
1. Be extremely careful not to damage the board during this process! Use a sharp set of pliers.
1. Locate the charging LED (CHR) and the powerLED (PWR) (see top view picture with the green rectangles)
1. Cut the soldering of the LED. The LED should come loose.
1. Remove the leds and check if the parts where removed cleanly without damaging the traces underneath.

## Step 5: #Hardware - Assembly 1: TSL2561 / BME680
        

### Parts:

- ***1x*** 3D print - "Node main body"
- ***1x*** Digital light sensor (small sensor)
- ***1x*** BME680 sensor (long sensor)
- ***2x*** Grove I2C connector cables
- ***4x*** M2x5 screws

### Instructions:

1. Connect one of the grove cables to the digital light sensor and the other to the BME680 sensor.
1. Place the sensors into the 3D print housing ("Node main body").
1. Digital light at the top left / BME680 at the top right. The connection part of the sensor is face down (not visible!). 
    - You have to bend the cables that they make a sharp turn.
1. And screw both into place with the m2x5 mm screws.

## Step 6: #Hardware - Assembly 2: Seeed LoRaWan Board 
         

### Parts:

- ***>*** The parts from step 5
- ***1x*** Battery tray with battery holders
- ***1x*** Seeed LoRaWan board
- ***4x*** M2x5 screws

### Instructions:

1. Insert the power cable of the battery tray into the LoRaWan board.
1. Bend the power cable over so the cables so they don't take up to much space.
1. Insert the LoRaWan board into the housing with the usb connector and power cable first.
1. Align the holes of the LoRaWan board with the mounting pins of the housing.
1. Make sure to place the LoRaWan board next to the dividing wall. (see pictures)
1. Insert the four screws into the indicated position of the board (see top view picture - Green circles)
1. When you tighten the screws make sure the reset button is properly aligned with the push button on the side of the node. (see top view picture - Blue rectangle)
1. Check if the reset button is properly working. 
    - If the button does not move or doesn't touch the reset button or the board there might be inconsistencies in the 3D print quality. Try moving the board slightly or consider breaking off the plastic printed reset button entirely to solve this. You can still reset the button trough the hole in the print.
1. Feed the antenna trough the foreseen opening in the battery support block, carefully thus not to break the antenna

## Step 7: #Hardware - Assembly 3: Connect I2C Pins
 

### Instructions:

1. Connect the Grove cables to the i2C slots on the Seeeduino. Only the two connectors closest to the edge are I2C pins and are usable for our sensors. But you may interchange both sensors connector. (see picture - blue rectangle)

## Step 8: #Hardware - Assembly 4: Cable Management - I2C Cables


### Instructions:

1. Behind the battery support block there is provided room to push the I2C cables down into. The fit is tight so they won't move back out.
1. Orient the cables nicely so they don't interfere with the battery tray that will be placed on top in a moment.

    > ***Comment: Leave the hardware of the node as is for now. We will setup the code first.***

## Step 9: #TTN - Sign Up / Log in
  

The things network provide a set of open tools and a global, open network to build your next IoT application at low cost, featuring maximum security and ready to scale.

> If you already have an account you can skip this step.

### Instructions:

1. Sign up at The Things Network and make an account
1. Follow the instruction on the TTN website.
1. After Sign up log in to your account
1. Go to your console. You will find it in the dropdown menu of your profile (see picture)

## Step 10: #TTN - Application Setup
 

> If you already have an application you can skip this step.

A application is an environment where you can store multiple node devices.

### Instructions:

1. When you are in the console click on applications (see picture 1).
1. Click on "add application"
1. You are now located in the add application window (see picture 2).
1. Make a Application ID
1. Give your Application a description
1. Set your handler registration (depending on your location)
1. When your done click "add application".

## Step 11: #TTN - Payload Formats Setup
 

The payload setup is important for reading your incoming data information correctly.

### Instructions:

1. In the application overview click on "Payload Formats". (see picture 1 - green rectangle)
1. Copy paste the [Payload format](/documentation/Payload_format.md) into the decoder editor. (see picture - blue rectangle)
1. Click on the save button to save your result.

## Step 12: #TTN - Add Devices
 

If everything goes well you are now in de Application overview where you have control over you application. 

We are now going to add a new device (node) to the application.

### Instructions:

1. Click on register device (see picture 1 - green rectangle)
1. Enter a Device ID
1. Set Device EUI to auto generated. Click on the crossing arrows on the left side.
1. When your done click on "register device".
    - The device is now created.

## Step 13: #TTN - Device Settings
    

This Step is really important to get a good connection of the LoRa setup of the devices.

### Instructions:

1. When you are in the device overview page click on "settings" (see picture 1 - green rectangle)
1. In the settings page you can give a description to your device (don't have to)
1. Set the activation mode to ABP.
1. Check off "Frame Counter checks". You will find on the bottom of the page.
1. Leave all the Device EUI, Device Address, Network Session Key, app session key to auto generation.
1. Click on the save button to save the new settings.
1. Go back to "settings" page. (see picture 3 - green rectangle)
1. Set the activation mode back to OTAA!! (see picture 4 - green rectangle)
1. Leave the App key to auto generation.
1. Click on the save button to save the new settings.(see picture 5 - green rectangle)
> This is a bit of a workaround that we needed to make this work properly. It should be possible without, but then we lost a lot of packages in TTN.

## Step 14: #Code - Arduino Code Download


Ok, so far so good. We have our node assembly, we have an account on the TTN, we created an application with the right payload format, and we made a device (OTAA) in that application. So now we only have to setup the Arduino code with the same settings information as the device we made in TTN. In the next step we will upload the code to the node.

### Instructions:

1. Download the mumoV1 directory from the Github page.
1. Download the latest version of the arduino IDE from [Arduino.cc](https://www.arduino.cc/en/software)
1. Open the arduino code file [`mumoV1.ino`](/Node/mumoV1)
    - Make sure to download the entire folder with all the files included.

## Step 15: #Code - Arduino - Device Setup With TTN
 

### Instructions:

1. Open thethingsnetwork (TTN), go to your device overview where you will find all the settings information of the device. We are going to use this for setup the arduino code.
1. In the arduino code go to "mumoV1.h" tab.

***Setup node ID:***

1. Copy the device_EUI from the TTN and paste it in the arduino code (see purple arrow).
1. Copy the application_EUI from the TTN and paste it in the arduino code (see blue arrow).
1. Copy the app_key from the TTN and paste it in the arduino code (see green arrow).If the network_session_key is not visible click on the "eye" symbol (see the green circle).
1. Copy the device_adress from the TTN and paste it in the arduino code (see yellow arrow).
1. Copy the network_session_key from the TTN and paste it in the arduino code (see orange arrow). If the network_session_key is not visible click on the "eye" symbol (see the orange circle).
1. Copy the app_session_key from the TTN and paste it in the arduino code (see red arrow). If the app_session_key is not visible click on the "eye" symbol (see the red circle).

## Step 16: #Code - Arduino - Install RTC and Adafruit Library
    

The components we use need libraries for them to work.

1. In you arduino interface click on Sketch > Include Library > Manage Libraries...

***The library management window will pop up.***
1. In the search bar type: rtczero
    - Install the latest version of the first library
1. In the search bar type: adafruit BME680 (For the BME680 sensor)
    - Install the latest version of the first library
1. In the search bar type: adafruit TSL2561 (For the TSL2561sensor)
    - Install the latest version of the first library.
1. In the search bar type: flashstorage ATSAM
    - Install the latest version of the first library.

## Step 17: #Code - Arduino - Seeeduino LoRaWAN Library Install
 

Also the board we use (Lorawan) needs to be added to Arduino to be able to programm it.

### Instructions:

1. In you arduino interface click on File > Preferences, and copy the url (underneath) to "Additional Boards Manager URLs" (see picture - red rectangle).
    `https://files.seeedstudio.com/arduino/package_seeeduino_boards_index.json`
1. Click on "ok".
1. Back at the arduino interface click on Tools > Board > Board Manager.
1. In the search bar type "lorawan".
1. You will see the library of Seeed LoRaWan board. (see picture - green rectangle).
1. Click on "install" and wait until it's done installing all dependancies.

## Step 18: #Code - Arduino - Board Selection / COM Port


### Instructions:

1. Connect the LoRaWAN board with a micro usb cable to your computer.
1. In you arduino interface click on Tools > Board and select the "Seeeduino LoRaWAN" board. (see picture)
1. Select in the same menu the correct COM port.

## Step 19: #Code - Arduino - Upload the Code to the Board


Now that we have our code ready, it's time to put the code on to the LoRaWAN board!

### Instructions:

1. Make sure your LoRaWAN board is still connected to your pc.
1. Double click the reset button on the side node. You will see that the led are flickering. This means that the device is in bootloader mode.
1. Because of the bootloader modus we might have to select a new COM port. This is done exacly the same as in Step 18.
1. Click on the upload button. It's the button with the arrow pointing to the right. (See picture - red circle).
1. After a while you should get an "upload done" notification in the bottom right corner.

## Step 20: #Code - Arduino - Test the Code!
 

### Instructions:

1. On the device overview of TTN click on "Data". There you will find all the incoming data that specific node device. (see picture - red rectangle)
1. To test the data transmission, press the reset button on the side of the node device to send signal.
1. If the LoRa signal is received by a gateway you will see the incoming data in you application data of the device on the TTN. (It might take a minute to see the result)
1. If you don't see incoming data try to push the rest button on the side of the node device again to re-send the signal again.
    - If this is not helping, you back to Step 18 and try to upload the code again.
    - You can open the terminal window in Arduino to check if no errors are showing up like bad connections to the sensors or obvious errors that the code can recognize.
1. Congrats you have now a working LoRa Node device!
1. Remove the USB cable from the lorawan board.
1. Push one last time on the rest button on the side of the node device.
    - This resets the led's so they don't stay lit.

## Step 21: #Hardware - Assembly 5: Insert Battery Tray
    

### Parts:

- ***>*** The assembly stack from step 6: Battery tray

### Instructions:

1. Insert the battery tray into the housing under an angle. Make sure you first position the power cable in the right direction. (see picture)
1. First position the tray on to the support block wall where the cables are stuffed behind.
1. Push the tray down until you hear a "snap click" sound.
1. Check the corner that the tray has a nice fit into the main housing. (see picture 2 / 3 - red circles) // weg
1. Insert the power cable on top of the I2C connection cables. 
    - If needed: Push it down with something blunt. 
    - ***Be careful not to damage the cables.***

## Step 22: #Hardware - Assembly 6: Insert Batteries
### Parts:

- ***6x*** AA batteries
### Instructions:

1. Insert the batteries into the battery holders.
1. make sure the batteries have decent contact.
> ***Side node: Check the battery orientation of the battery holder. This may vary per tray type.***

## Step 23: #Hardware - Assembly 7: Back Cover


### Parts:

- ***1x*** 3D print - Back cover node
### Instructions:

1. Insert the back cover lips into the lip grove of the main body housing under a slide angle.
1. Push on the side of the housing and make sure it is is the right position.
1. If the lips are not fitting because of print issues try to grind some of the surface until it fits. 
    - Check that the back cover is completely flat on the housing and that there are no open seams.
1. Insert the M3x12mm screws and tighten.

## Step 24: #Hardware - Attachment of the Device
    

There are several ways to attach the device:
- Screw slide lock groove on the side.
- Screw slide lock groove on the back.
- Tiewrap groves on the side / top and back.
- And the backcover of the node is also provided with a hook.

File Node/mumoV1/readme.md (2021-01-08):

This is the Arduino code for the node.

### In the main file (mumoV1):
> ### Registration keys
>You have to insert your registration codes from TTN: (Device EUI, Application EUI, App key, Device address, Network session key en app session key

> ### Base thresholds that activate an alarm
>Also you can define base values when the device should go into alarm mode and start transmitting data every minute instead of the regular interval.
>Be carefull not setting these values too narrow. Since being in alarm mode costs a lot more energy.

>> Temperature min and max ranging from 0 to 255°C as an integer value (no decimal values)

>> Relative humidity min and max ranging from 0 to 100% as an integer value

>> Illumination maximum randing from 0 to 40.000 LUX as an integer value

>> Barometric air pressure as a difference from 101325 Pa atmosferic pressure in Pa and as an integer value

> ### base transmission frequency
>Finally you can set the base_sleepCycli. This means every how many minutes a data transmission will be send to TTN.
>Also here, a higher values means a longer life time of the device

### Downlink 
Using a downlink package these values can be changed after installation of the devices.

### Alterations
We advice not to change anything after this point in the file. But if required any other sensors can be added in the code.
* Initilisation in the defines.h file.
* Setup in the mumoV1.ino file.
* And combining the measurements into the data package in the combine_data.ino file.

## To change the location (EU, VS, AU, ...) and the channels 
* check halfway the setup section in mumoV1.ino file.

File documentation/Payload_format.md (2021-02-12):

# The Things Network Payload format

### Decoder
upload this code in to the decoder tab of the application:
```
function Decoder(bytes, port) {
  // Decode an uplink message from a buffer
  // (array) of bytes to an object of fields.
  var decoded = {};

  decoded.version = bytes[0];
  if(decoded.version == 1){
    decoded.battery = bytes[1];
    decoded.humidity = bytes[2];
    decoded.humidity += (bytes[3]/100);
    decoded.temperature = bytes[4];
    decoded.temperature += (bytes[5]/100);
    decoded.pressure = (bytes[6])<<8;
    decoded.pressure += (bytes[7]);
    decoded.pressure =  (decoded.pressure-30000+101325)/100;
    decoded.illumination = (bytes[8]<<8);
    decoded.illumination += bytes[9];
  }
  return decoded;
}
```

# Human readable format
## Uplink
#### BIT: ACTION
- 0: version number (For now V1)
- 1: Battery level (indication)[0-100%]
- 2: Air moisture (above decimal place)[0 - 255%]
- 3: Air moisture (after decimal place)[0.00-0.99% * 100]
- 4: Air Temperature ((above decimal place)[0 - 255°C]
- 5: Air Temperature (after decimal place)[0.00-0.99°C * 100]
- 6: Air pressure (Big byte << 8)[offset from baseline 101325 pA pressure]
- 7: Air pressure (Small byte) 
- 8: Lux (Big byte)[]
- 9: Lux (Small byte)

## Downlink
#### BIT: ACTION
- 0: Maximal temperature (devided by 5)[0-50°C => 0-250]
- 1: Minimal temperature (devided by 5)[0-50°C => 0-250]
- 2: Maximal humidity (devided by 2)[0-100% = 0-200]
- 3: Minimal humidity (devided by 2)[0-100% = 0-200]
- 4: Maximal light (Big byte)[0-65000 Lux]
- 5: Maximal light (Small byte)
- 6: Maximal pressure offset (Big byte)[offset from baseline 101325 Pa pressure]
- 7: Maximal pressure offset (Small byte)
- 8: Sleepcycle (minutes between data transmissions)[0-255 minutes]

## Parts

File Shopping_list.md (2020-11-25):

# Node

<table>
    <tr>
        <th>Beschrijving</th>
        <th>Aantal</th>
        <th>Richtprijs<br/>Incl. btw.</th>
        <th>Voorbeeld<br/>Webshop links</th>
    </tr>
    <tr>
        <td>Seeeduino LoRaWan</td>
        <td>1</td>
        <td>€ 43</td>
        <td>
            <a href="https://www.kiwi-electronics.nl/seeeduino-lorawan">Kiwi</a>
            |
            <a href="https://www.mouser.be/ProductDetail/713-102010128">Mouser</a>
            |
            <a href="https://www.seeedstudio.com/Seeeduino-LoRaWAN-p-2780.html">Seeed</a>
        </td>
    </tr>
    <tr>
        <td>Battery holder 3x AA</td>
        <td>2</td>
        <td>€ 3</td>
        <td>
            <a href="https://www.mouser.be/ProductDetail/534-2465">Mouser</a>
        </td>
    </tr>
    <tr>
        <td>Seeed BME680 sensor</td>
        <td>1</td>
        <td>€ 22</td>
        <td>
            <a href="https://www.kiwi-electronics.nl/grove-bme680-module">Kiwi</a>
            |
            <a href="https://www.mouser.be/ProductDetail/713-101020513">Mouser</a>
            |
            <a href="https://www.seeedstudio.com/Grove-Temperature-Humidity-Pressure-and-Gas-Sensor-for-Arduino-BME680.html">Seeed</a>
        </td>
    </tr>
    <tr>
        <td>Seeed digital light sensor</td>
        <td>1</td>
        <td>€ 11</td>
        <td>
            <a href="https://www.kiwi-electronics.nl/grove-digital-light-sensor">Kiwi</a>
            |
            <a href="https://www.mouser.be/ProductDetail/713-101020030">Mouser</a>
            |
            <a href="https://www.seeedstudio.com/Grove-Digital-Light-Sensor-TSL2561.html">Seeed</a>
        </td>
    </tr>
    <tr>
        <td>Rechargeable AA batteries<br/>of good capacity (+2000 mAh)</td>
        <td>6</td>
        <td>€ 11-30</td>
        <td>
            <a href="https://www.ikea.com/be/nl/p/ladda-oplaadbare-batterij-70303876/">Ikea</a>
            |
            <a href="https://www.kiwi-electronics.nl/gp-nimh-recyko-batterij-2600mah-aa-4-pack">Kiwi</a>
        </td>
    </tr>
    <tr>
        <td>Wood screw 3 x 12</td>
        <td>2 st</td>
        <td>€ 3 (100)</td>
        <td><a href="https://www.rvspaleis.nl/bouten/kruisgleuf/din-965/din-965-[-]-a2-[-]-m3/965-2-3x16_100">RVS-paleis</a></td>
    </tr>
    <tr>
        <td>Small bolt M2 x 5</td>
        <td>8 st</td>
        <td>€ 3 (100)</td>
        <td><a href="https://www.rvspaleis.nl/bouten/kruisgleuf/din-7985/din-7985-[-]-a2-[-]-m2/7985-2-2x5_100">RVS-paleis</a></td>
    </tr>
    <tr>
        <td>Shrinking sleeves</td>
        <td>1</td>
        <td></td>
        <td></td>
    </tr>
    <tr>
        <td>3D printed housing<br/>in PLA, PetG or ABS</td>
        <td>1</td>
        <td></td>
        <td></td>
    </tr>
    <tr>
        <td></td><td>Totaal:</td><td>€ 100</td><td></td>
    </tr>
</table>

<code>*Non tested versions</code>

# Gateway

### You can either choose for a plug and play gateway
<table>
    <tr>
        <th>Beschrijving</th>
        <th>Aantal</th>
        <th>Richtprijs<br/>Incl. btw.</th>
        <th>Voorbeeld<br/>Webshop links</th>
    </tr>
    <tr>
        <td>THE THINGS INDOOR<br/>LORAWAN GATEWAY</td>
        <td>1</td>
        <td>€ 96</td>
        <td>
            <a href="https://www.seeedstudio.com/The-Things-Indoor-Gateway-EU-p-4709.html">Seeed</a>
            |
            <a href="https://www.antratek.be/the-things-indoor-gateway">Antratek</a>
        </td>
    </tr>
</table>

### Or make a custom gateway with extra abilities integrated:
<table>
    <tr>
        <th>Beschrijving</th>
        <th>Aantal</th>
        <th>Richtprijs<br/>Incl. btw.</th>
        <th>Voorbeeld<br/>Webshop links</th>
    </tr>
    <tr>
        <td>Raspberry Pi<br/>Model 3 B+</td>
        <td>1</td>
        <td>€ 40</td>
        <td>
            <a href="https://www.kiwi-electronics.nl/raspberry-pi-3-model-b-plus">Kiwi</a>
            |
            <a href="https://www.mouser.be/ProductDetail/358-RPI3-MODBP-BULK">Mouser</a>
        </td>
    </tr>
    <tr>
        <td>Sd kaartje</td>
        <td>1</td>
        <td>€ 12</td>
        <td>
            <a href="https://www.kiwi-electronics.nl/16gb-noobs-microsd">Kiwi</a>
            |
            <a href="https://www.antratek.com/32gb-microsdhc-card-sd-adapter">Antratek</a>
            |
            <a href="https://www.mouser.be/ProductDetail/474-COM-15052">Mouser</a>
        </td>
    </tr>
    <tr>
        <td>Power supply<br/>5V micro usb</td>
        <td>1</td>
        <td>€ 11</td>
        <td>
            <a href="https://www.kiwi-electronics.nl/rpi-psu-5-1v-2-5a--eu-uk">Kiwi</a>
            |
            <a href="https://www.antratek.com/microusb-adapter-5v-2a">Antratek</a>
            |
            <a href="https://www.mouser.be/ProductDetail/358-1101001000045">Mouser</a>
        </td>
    </tr>
    <tr>
        <td>Lorawan concentrator</td>
        <td>1</td>
        <td>€ 110</td>
        <td>
            <a href="https://www.antratek.com/10-channels-lorawan-gps-concentrator-for-raspberry-pi">Antratek</a>
            |
            <a href="https://www.mouser.be/Electronic-Components/">Mouser</a>
            |
            <a href="https://www.seeedstudio.com/Dragino-10-channels-LoRaWAN-GPS-Concentrator-for-Raspberry-Pi-p-4481.html">Seeed</a>
        </td>
    </tr>
    <tr>
        <td>Grove hat²</td>
        <td>1</td>
        <td>€ 12</td>
        <td>
            <a href="https://www.kiwi-electronics.nl/ss-103030275">Kiwi</a>
            |
            <a href="https://www.mouser.be/ProductDetail/713-103030275">Mouser</a>
            |
            <a href="https://www.seeedstudio.com/Grove-Base-Hat-for-Raspberry-Pi-p-3186.html">Seeed</a>
        </td>
    </tr>
    <tr>
        <td>Pi night-vision camera</td>
        <td>1</td>
        <td>€ 27</td>
        <td>
            <a href="https://www.kiwi-electronics.nl/raspberry-pi-night-vision-camera">Kiwi</a>
            |
            <a href="https://www.mouser.be/ProductDetail/713-114990837">Mouser</a>
        </td>
    </tr>
    <tr>
        <td>Seeed air dust sensor</td>
        <td>1</td>
        <td>€ 15</td>
        <td>
            <a href="https://www.kiwi-electronics.nl/grove-dust-sensor">Kiwi</a>
            |
            <a href="https://www.mouser.be/ProductDetail/713-101020012">Mouser</a>
        </td>
    </tr>
    <tr>
        <td>Seeed BME680 sensor</td>
        <td>1</td>
        <td>€ 22</td>
        <td>
            <a href="https://www.kiwi-electronics.nl/grove-bme680-module">Kiwi</a>
            |
            <a href="https://www.mouser.be/ProductDetail/713-101020513">Mouser</a>
            |
            <a href="https://www.seeedstudio.com/Grove-Temperature-Humidity-Pressure-and-Gas-Sensor-for-Arduino-BME680.html">Seeed</a>
        </td>
    </tr>
    <tr>
        <td>Seeed digital light sensor</td>
        <td>1</td>
        <td>€ 11</td>
        <td>
            <a href="https://www.kiwi-electronics.nl/grove-digital-light-sensor">Kiwi</a>
            |
            <a href="https://www.mouser.be/ProductDetail/713-101020030">Mouser</a>
            |
            <a href="https://www.seeedstudio.com/Grove-Digital-Light-Sensor-TSL2561.html">Seeed</a>
        </td>
    </tr>
    <tr>
        <td>Outside bolt M3 x 16</td>
        <td>2 st</td>
        <td>€ 3 (100)</td>
        <td><a href="https://www.rvspaleis.nl/bouten/kruisgleuf/din-965/din-965-[-]-a2-[-]-m3/965-2-3x16_100">RVS-paleis</a></td>
    </tr>
    <tr>
        <td>Small bolt M2 x 5</td>
        <td>8 st</td>
        <td>€ 3 (100)</td>
        <td><a href="https://www.rvspaleis.nl/bouten/kruisgleuf/din-7985/din-7985-[-]-a2-[-]-m2/7985-2-2x5_100">RVS-paleis</a></td>
    </tr>
    <tr>
        <td>Long bolt M3 x 40</td>
        <td>aantal</td>
        <td>€ prijs</td>
        <td>
            <a href="https://www.rvspaleis.nl/bouten/kruisgleuf/din-7985/din-7985-[-]-a2-[-]-m3/7985-2-3x40_50">RVS-paleis</a>
        </td>
    </tr>
    <tr>
        <td>3D printed housing<br/>In PetG or ABS</td>
        <td>1</td>
        <td></td>
        <td>
        </td>
    </tr>
    <tr>
        <td></td><td>Totaal:</td><td>€ 260</td><td></td>
    </tr>
</table>

² This board can be replaced with a <a href="https://www.seeedstudio.com/Grove-Base-Hat-for-Raspberry-Pi-Zero.html">hat for a raspberry pi zero<a> and a <a href="https://www.seeedstudio.com/Grove-I2C-Hub.html"> i2c hub</a>

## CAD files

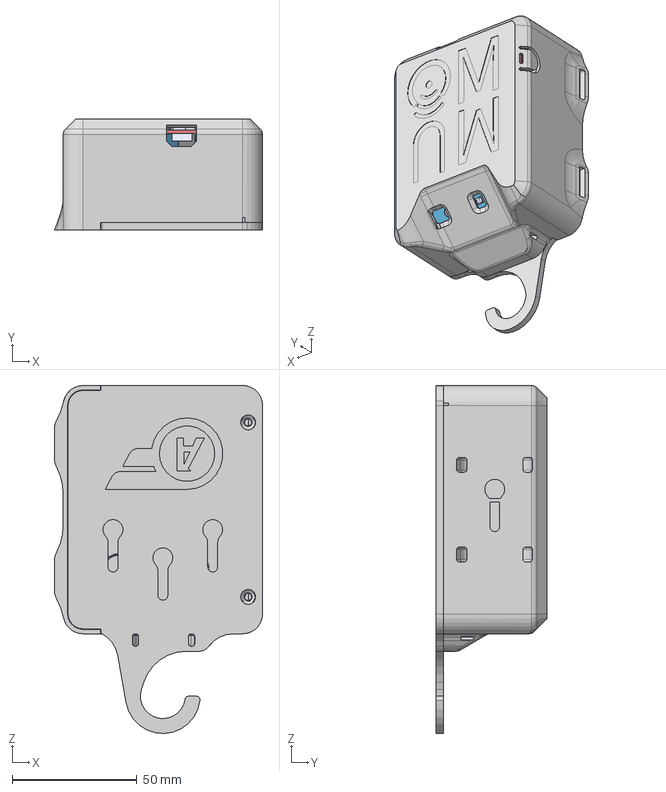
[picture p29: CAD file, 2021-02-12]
Node/CAD_FILES/NODE_Assembly_STEP.step
83.5 x 44.6 x 139.6 mm
PCB (small)
Connecteur Grove (debout)
condensateur x 3
PCB (Medium)
Connecteur Grove (flat)
condensateur_1 x 3
Part1^BME680
Battery tray
Backcover
Backcover _with_hook v2
Seeeduino board_1

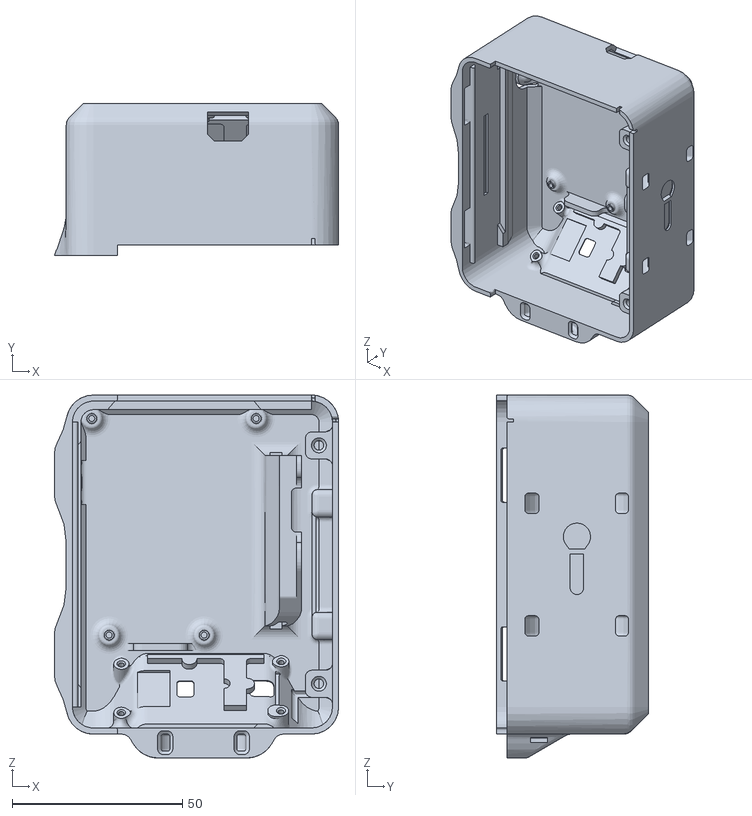
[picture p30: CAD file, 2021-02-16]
Node/STL_NODE/NODE_Main_Housing_V2.stl
83.5 x 44.6 x 106.6

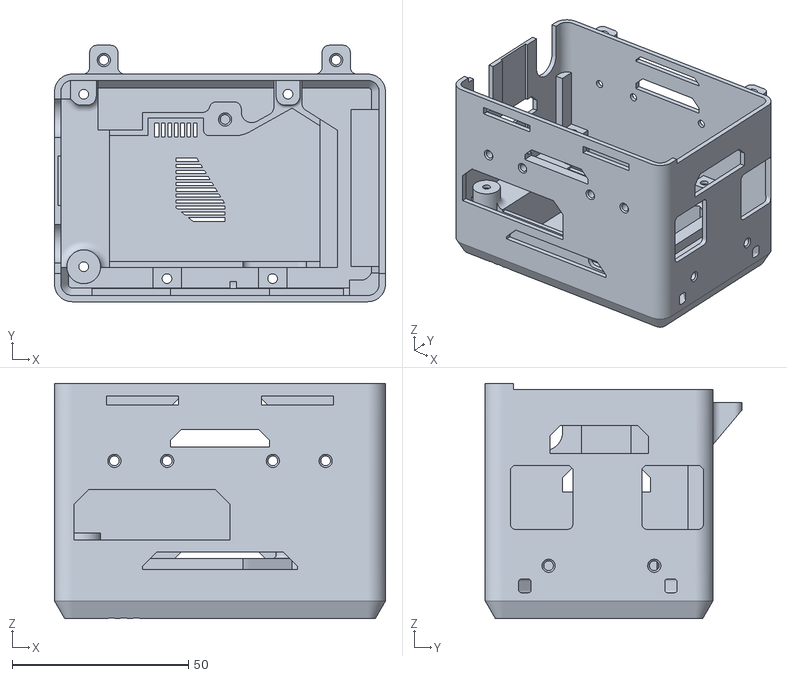
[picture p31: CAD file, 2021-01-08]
Gateway/STL_GATEWAY/GATEWAY_Main_Housing.stl
94.0 x 72.9 x 66.8

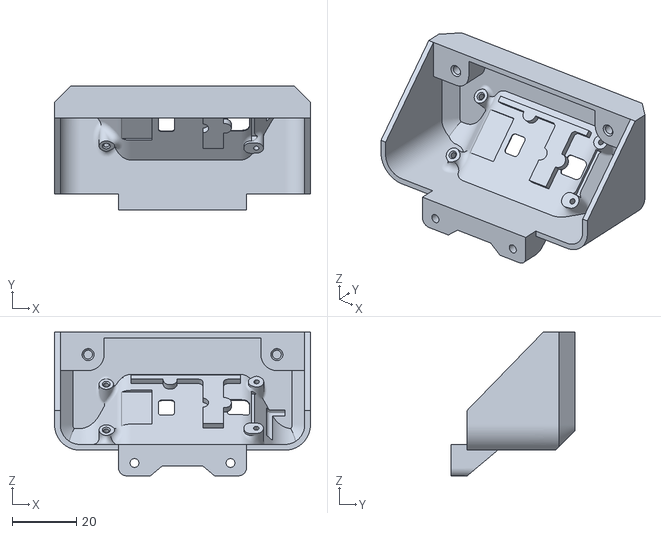
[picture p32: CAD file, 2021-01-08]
Gateway/STL_GATEWAY/Sensor_Housing.stl
80.0 x 38.6 x 44.9

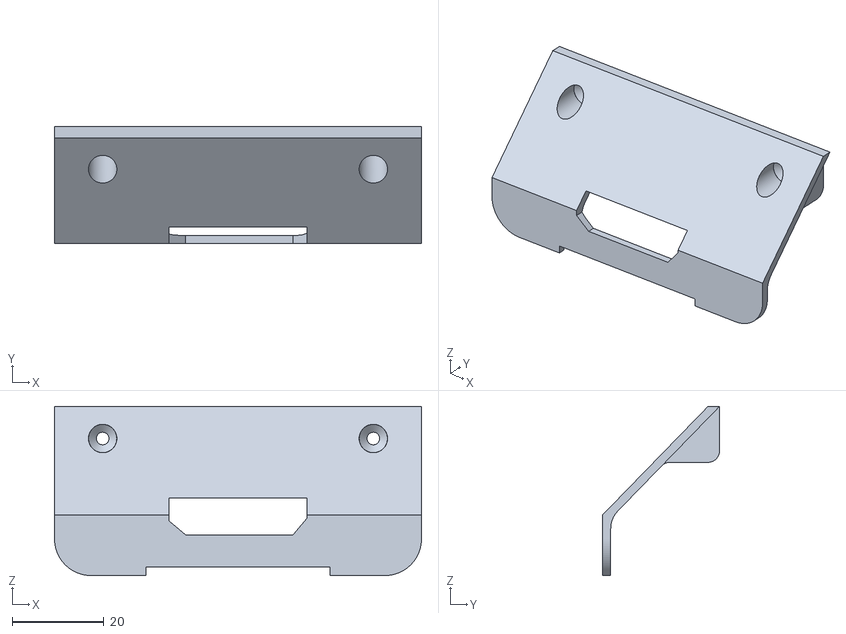
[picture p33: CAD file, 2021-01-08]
Gateway/STL_GATEWAY/Sensor_Backcover.stl
80.0 x 25.5 x 36.9

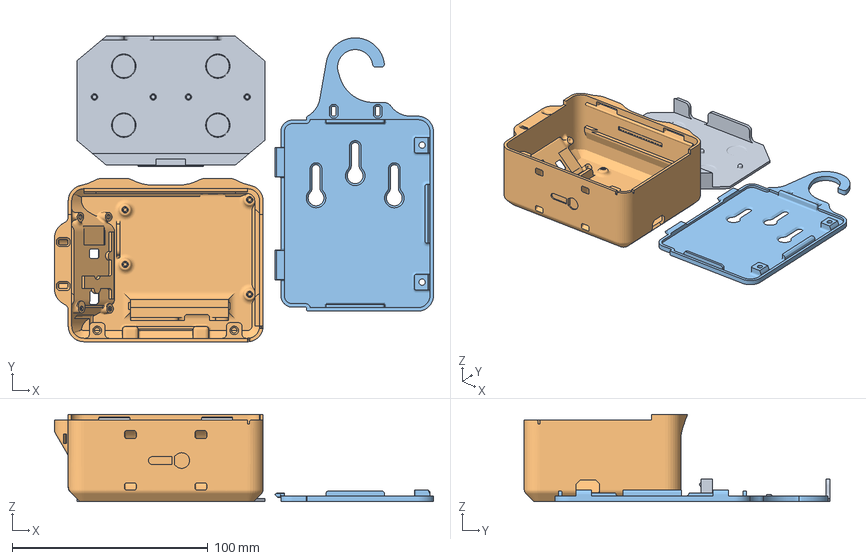
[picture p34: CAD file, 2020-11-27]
Node/STL_NODE/NODE.3mf
193.6 x 156.1 x 44.6 mm
NODE_Battery_Tray.stl
NODE_Main_Housing.stl
NODE_Backcover.stl

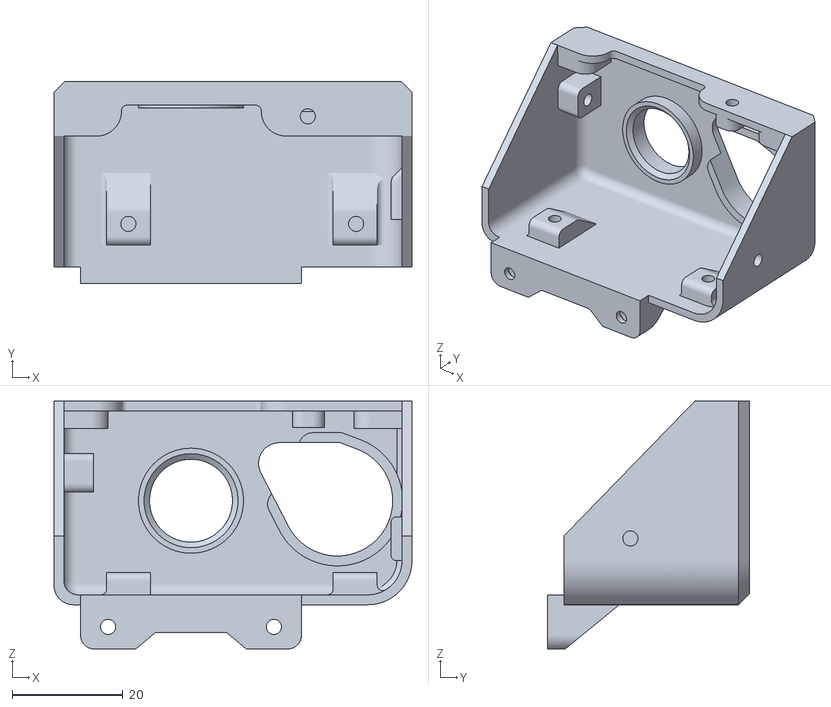
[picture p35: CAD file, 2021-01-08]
Gateway/STL_GATEWAY/Camera_Housing.stl
64.8 x 36.6 x 44.9

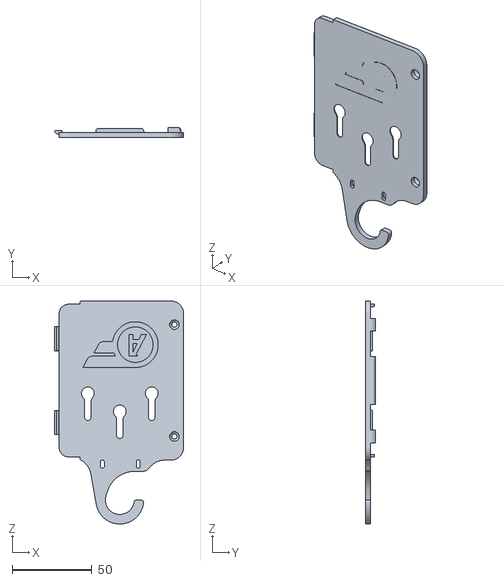
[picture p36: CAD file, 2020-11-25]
Node/STL_NODE/NODE_Backcover.stl
81.0 x 6.00 x 139.6

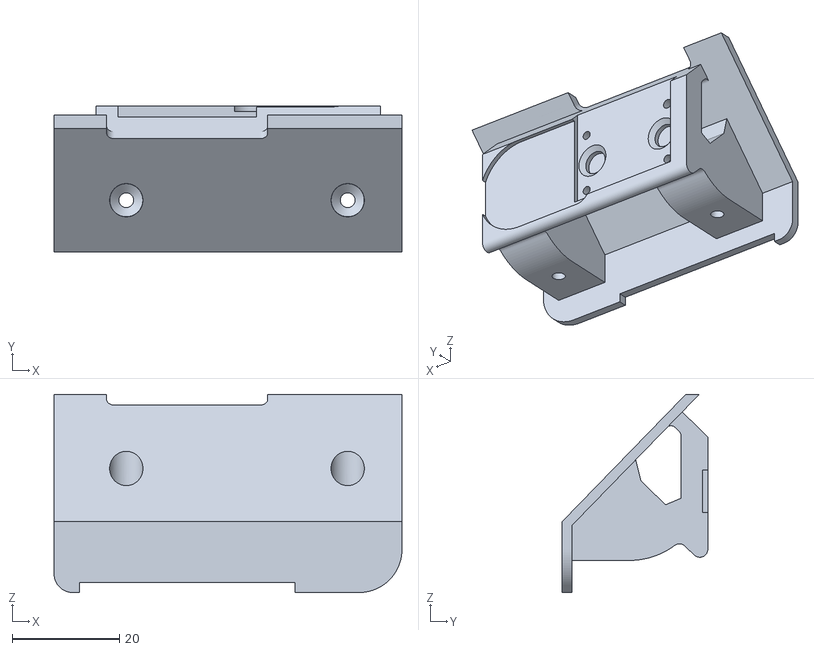
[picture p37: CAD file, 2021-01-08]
Gateway/STL_GATEWAY/Camera_Backcover.stl
64.8 x 27.1 x 36.9

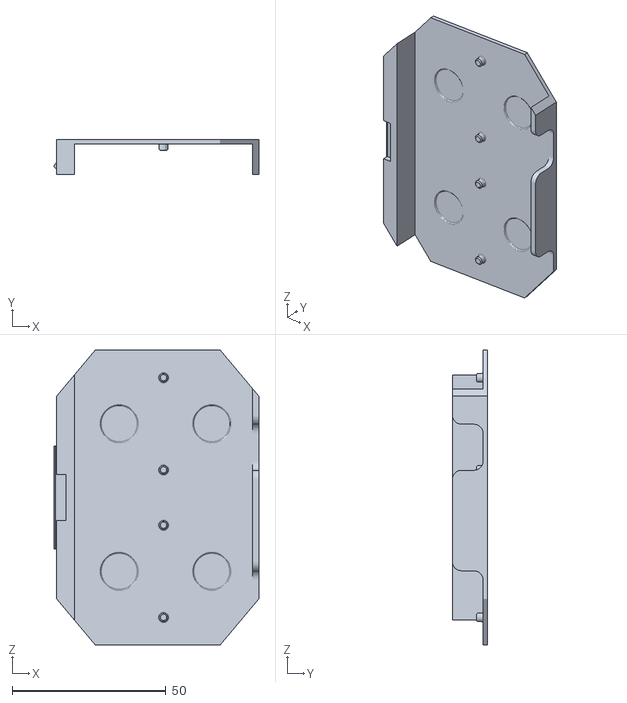
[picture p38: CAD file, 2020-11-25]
Node/STL_NODE/NODE_Battery_Tray.stl
66.6 x 11.5 x 96.0

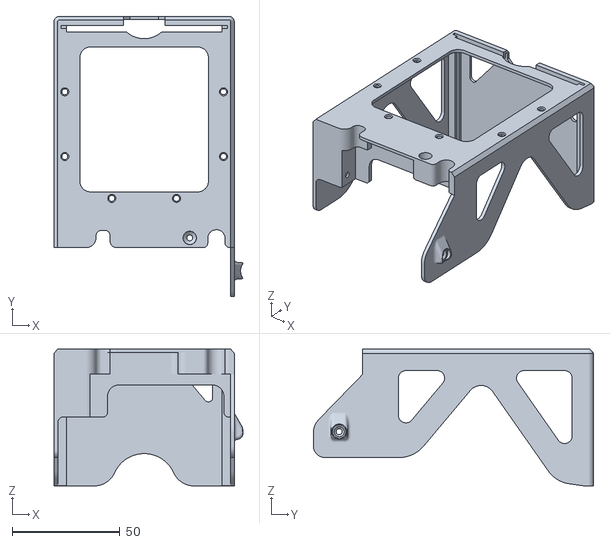
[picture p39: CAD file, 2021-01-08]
Gateway/STL_GATEWAY/Bug_Trap.stl
87.6 x 130.0 x 63.5

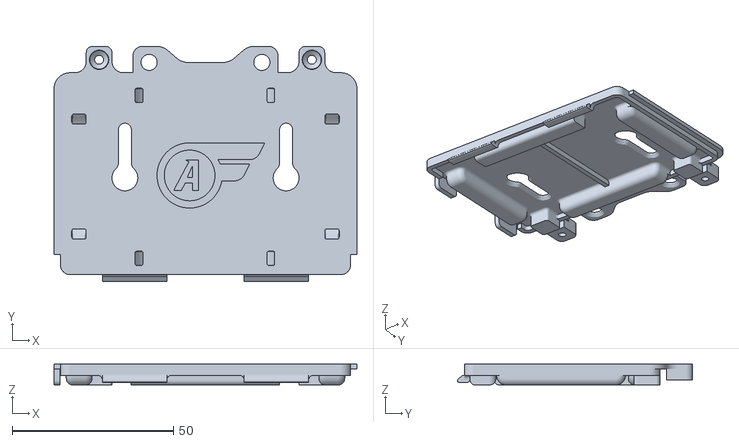
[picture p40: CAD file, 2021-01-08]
Gateway/STL_GATEWAY/GATEWAY_Backcover.stl
94.0 x 73.1 x 6.50

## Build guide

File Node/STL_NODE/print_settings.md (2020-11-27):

# Print settings:
- PLA or PETG (PLA has a cleaner print quality, but PETG is more durable)
- 0.15 to 0.2 mm layer height
- 2 or 3 perimeters (depending on how tough you want the device to be)
- No supports needed

> Use either the Prusa project file (.3mf) or the seperate .stl files

### Print orietations:
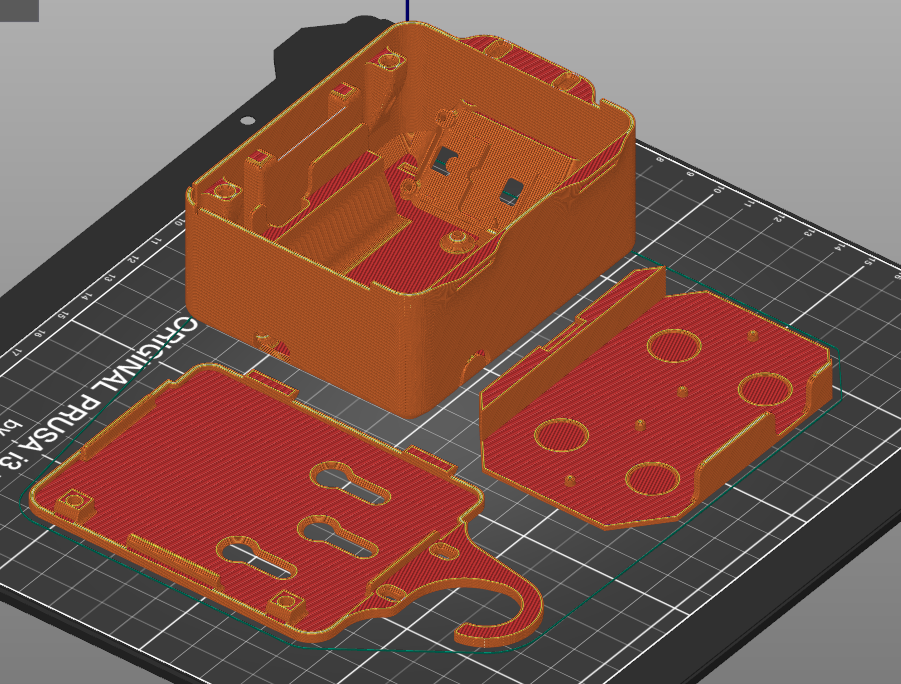
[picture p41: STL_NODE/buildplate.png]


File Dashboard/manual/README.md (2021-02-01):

<h1>Mumo Dash</h1>
Introduction...

<h1>Credits:</h1>

<h1>Browser Support:</h1>

- Chrome 
- FireFox 
- Safari 
-...

<h1>License Information:</h1>

<h1>How to use Mumo Dash?</h1>

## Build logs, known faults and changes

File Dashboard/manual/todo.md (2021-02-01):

# Todo:
## long done
- [x] Pictures history
- [x] Fix icon alignments (mainly on the battery icons)
- [x] Iframe page
- [x] Hash date into url to check if recent. Also protection method.
- [x] Battery level into some levels
- [x] unregistered device krijgt geen naam op sensor pagina. Hier unregistered of de UID geven
- [x] Er is slechts 1 foto zichtbaar bij de bug detectie momenteel
- [x] Tijdsrange limiteren (momenteel bij node 7 een tijdswaarde van -20000)
- [x] group op main level niveau slaat NULL op als 0 en werkt dus niet
- [x] Lege device naam mag momenteel, maar ziet er vreemd uit in weergaven. Dus of null houden of naam verplichten.
- [x] external url is altijd getoont na de naam. Hoort enkel indien er iets ingegeven is
- [x] Een dag toevoegen aan de grafieken. Of de code neemt de data tot 00:00 in de ochtend van de dag
- [x] Thresholds nakijken en alerts sturen
- [x] Bij alert nakijken of dezelfde alert al niet actief is.
- [x] notifications lijst weergeven
- [x] per sensor een geschiedenis van notifications weergeven
- [x] Group deleten zorgt ervoor dat subgroups verdwijnen. Subgroups aanpassen naar main group!
## recently done
- [x] Dust and VOC was sometimes mixed up
- [x] Global settings zijn lokaal aanpasbaar.
- [x] batterijalarm niet gewenst bij de gateways
- [x] Users privileges are not updated to database correctly
- [x] Frame counter terug activeren
- [x] Admin privileges
- [x] Indien alert gedaan maar er nog een open staat einde mailen...
- [x] Signaalsterkte verwerken tot iets nuttigs
- [x] Show endpoint url
- [x] Time alerts werken nog niet denk ik?
- [x] Gap in grafiek door Null data in te geven bij een gap
- [x] Data export van data
- [x] endpoint url checken of cleanen
- [x] Keuze of metingen met of zonder 0 punt in grafiek staan
- [x] endpoint -> Url met sluitende / of niet. en http://www.site.be of http://mumo.site.be
## open
- [ ] Tijdszone instelling (server tijd tov pc tijd tov sql)
- [ ] Update calibration nulls if code version changes
- [?] sensor deleten -> Niet deleten maar offline maken zodat nieuwe data er terug bij kan komen (3 standen, actief, tijdelijk uit, permanent weg)
- [x] Allow time selection to be disabled on an iframe page
- [x] Iframe opties uitbreiden (welke weergaven, tijdsframe, ...)
- [x] Wat als gebruiker verwijderd is. Slaat het mailsysteem tilt? -> Nee, die skipped em.
- [x] Gebruiker delete optie

## extra
- [-] Uplink van threshold instellingen of enkel tijdinstelling
- [-] Plotse pieken detecteren

## Hardware
- [ ] Alerts instellingen in de uitleg bij assemblage van de node
- [ ] Hoekje van de support blok => en afschuining op gaten
- [ ] The Things Network Payload format los van de uitleg over die Payload
- [ ] L led knipperen in error

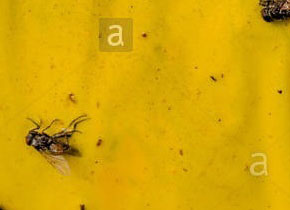
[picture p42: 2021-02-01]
Dashboard/assets/images/bug/mottrap_2.jpg

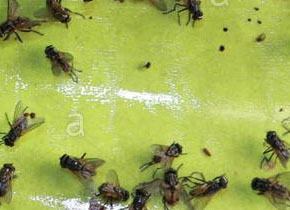
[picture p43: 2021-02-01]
Dashboard/assets/images/bug/mottrap_1.jpg

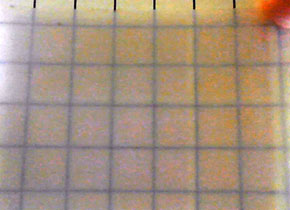
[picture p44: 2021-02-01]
Dashboard/assets/images/bug/mottrap_3.jpg

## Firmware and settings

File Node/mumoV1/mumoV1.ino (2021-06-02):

//############   TTN SETTINGS   #######################################################
#define device_EUI "0034CB1F3A1E17FE"
#define application_EUI "70B3D57ED0037085" //This might also be called JOIN_EUI in the new TTN.
#define app_key "F10A9C97FF857E350092E410745AE7A9"

#define device_address "26011300"
#define network_session_key "1ACC5ADE5AFFCD5FED6EF37543B4604D"
#define app_session_key "6DC61FB498B1AAE158D63475F5298B64"

//############   SENSOR SETTINGS   ###################################################
//Sensor thresholds (FlashStorage overwrite with downlink) -----------
#define allow_downlink true
#define base_maximal_temperature 35
#define base_minimal_temperature 8
#define base_maximal_humidity 70
#define base_minimal_humidity 15
#define base_maximal_illumination 1000
#define base_range_pressure 22000
#define base_sleepCycli 15

//############   CODE INFORMATION   ###################################################
int Version = 1;

/*- DO NOT EDIT THE CODE BELOW THIS LINE -*/
#include "defines.h"

void setup(void) {
  Serial.begin(115200);

  // LoRaWan Board hardware settings
  for (unsigned char i = 0; i < 26; i ++) { // Important, set all pins to HIGH to save power during sleeps
    pinMode(i, OUTPUT);
    digitalWrite(i, HIGH);
  }
  pinMode(38, OUTPUT); //Specifically turn pin 38 OUTPUT and HIGH to activate the Grove connectors
  digitalWrite(38, HIGH);

  //-- Starting both I2C sensors (bme and tsl) --//
  Wire.begin();
  if (!bme.begin(0x76) || !tsl.begin()) {
    Serial.println("Check wiring of the sensors!");
    while (1); //Eternal loop when disconnected
  }

  //-- Set up BME680 oversampling and filter initialization --//
  bme.setTemperatureOversampling(BME680_OS_8X); //1,2,4,8 of 16X
  bme.setHumidityOversampling(BME680_OS_8X); //1,2,4,8 of 16X
  bme.setPressureOversampling(BME680_OS_4X); //1,2,4,8 of 16X
  bme.setIIRFilterSize(BME680_FILTER_SIZE_0); //Filter size for the resistance? 0, 1, 3, 7, 15, 31, 63, 127
  /* Disabled the GAS heater to save power. */
  bme.setGasHeater(0, 0); // 0*C for 0 ms

  //-- Set up TSL2561 oversampling and gain --//
  tsl.setGain(TSL2561_GAIN_16X);
  tsl.setIntegrationTime(TSL2561_INTEGRATIONTIME_13MS);

  // Set default thresholds to the flash memory if the downlink boolean is false, so no change with downlink value
  if (downlink_occured.read() == false) {
    maximal_temperature.write(base_maximal_temperature);
    minimal_temperature.write(base_minimal_temperature);
    maximal_humidity.write(base_maximal_humidity);
    minimal_humidity.write(base_minimal_humidity);
    maximal_illumination.write(base_maximal_illumination);
    range_pressure.write(base_range_pressure);
    sleepCycli.write(base_sleepCycli);
  }

  //-- Start Lora module --//
  lora.init();

  lora.setId(device_address, device_EUI, application_EUI); //devaddr, devEUI, appEUI
  lora.setKey(network_session_key, app_session_key, app_key); //nwkskey, appskey, appkey

  lora.setDeciveMode(LWOTAA);

  lora.setDataRate(DR0, EU868);
  lora.setAdaptiveDataRate(true);

  lora.setChannel(0, 868.1);
  lora.setChannel(1, 868.3);
  lora.setChannel(2, 868.5);
  lora.setChannel(3, 867.1);
  lora.setChannel(4, 867.3);
  lora.setChannel(5, 867.5);
  lora.setChannel(6, 867.7);

  lora.setReceiceWindowFirst(869.5, DR3);
  lora.setReceiceWindowSecond(869.5, DR3);

  lora.setPower(20);

  //Ping the TTN server to JOIN
  while (!lora.setOTAAJoin(JOIN));
  digitalWrite(LED_BUILTIN, LOW); //Turn the onboard led off now that we are joined

  //RTC zetten
  rtc.begin(false);
  nextAlarmClock = rtc.getEpoch() + 60; // calculate the time of the first alarm (in one minute)
  rtc.setAlarmEpoch(nextAlarmClock);
  rtc.enableAlarm(rtc.MATCH_SS); //check the alarm based on seconds, so we wake up every minute

  delay(500);
  //perform first measurement on all sensors
  check_measurements();
  delay(500);
}

void loop(void) {
  Serial.println("########################## LOOP SEQUENCE #################################");

  if (loraSending() && allow_downlink) { //return downlink data received
    update_thresholds(); // change the threshold values in the flash if allowed
  }

  delay(20);
  Serial.println("Lora into sleep modus");
  lora.setDeviceLowPower();     // turn the LoRaWAN module into sleep mode

  for (int i = 0; i < sleepCycli.read() ; i++) { // 10 sleep cycli of 60 seconds

    doSleep(); //sleep for one minute

    if (check_measurements()) { //an alarm was raised. Cut the sleepcycle and straight to send!
      alarm = true;
      break;
    } else if (alarm) { //no alarm this time, but in case the last time was; send once more
      alarm = false;
      break;
    }
  }
} // end of loop

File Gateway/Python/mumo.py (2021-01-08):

#! /usr/bin/python3
# This code is being started from /etc/xdg/lxsession/LXDE-pi/autostart. Backup options was trough /home/pi/.bashrc
import time
import board
from busio import I2C
import adafruit_bme680
import adafruit_tsl2561
import numpy as np
import RPi.GPIO as GPIO
import cv2
import requests
import base64
import schedule
import os
import subprocess
from getmac import get_mac_address

URL = "insert url to the server here!"
code_version = "2"
framecounter = 0
GPIO.setup(16, GPIO.IN, pull_up_down = GPIO.PUD_DOWN)
input = GPIO.input(16)
i2c = I2C(board.SCL, board.SDA)
bme680 = adafruit_bme680.Adafruit_BME680_I2C(i2c, 0x76, debug=False)
tsl2561 = adafruit_tsl2561.TSL2561(i2c, 0x29)
tsl2561.gain = 1 # 1 = 16x
tsl2561.integration_time = 2 # 2 = 402ms, 1 = 101ms, 0 = 13.7ms
wlan_check_flag = False
mac_address = get_mac_address(interface="wlan0")

def wlan_check():
    global wlan_check_flag
    if wlan_check_flag:
        print("long term issue, reboot")
        subprocess.call(['logger "wlan down, forcing a reboot"'], shell=True)
        wlan_check_flag = False
        subprocess.call(['sudo reboot'], shell=True)
    else:
        print("trying to recover connection")
        subprocess.call(['logger "Wlan is down, try a reconnect"'], shell=True)
        wlan_check_flag = True
        subprocess.call(['sudo /sbin/ifdown wlan0 && sleep 10 && sudo/sbin/ifup --force wlan0'], shell=True)

def take_picture():
    print("smile!")
    cap = cv2.VideoCapture(0)

    for x in range(5):
        ret, img = cap.read()
        time.sleep(1)
    cap.release()
    #save latest high res image
    cv2.imwrite("/home/pi/Desktop/code/high_res.jpg", img)

    height = 75
    scale = img.shape[0]/height
    width = int(img.shape[1] / scale)
    dim = (width, height)
    img = cv2.resize(img, dim, interpolation = cv2.INTER_AREA)
    _, img_arr = cv2.imencode('.jpg', img)
    img_bytes = img_arr.tobytes()
    img_b64 = base64.b64encode(img_bytes)
    try:
        x = requests.post(URL, data={"device_ID":mac_address, "version": code_version, "img":img_b64})
        wlan_check_flag = False   
        print(x.text)
    except requests.exceptions.ConnectionError as err:
        print ("request failed:", err)
        wlan_check()

def read_sensors():
    global framecounter
    print("starting measurements")
    counter = 0
    for x in range(55000): # this gives about 60sec measurement
        time.sleep(0.001)
        if GPIO.input(16) == 0:
            counter = counter+1
    percentage = counter / 550 # devide by the same 55000 and multiply by 100 to get %
    
    percentage = "null" if percentage is None else round(percentage,2)
    
    temp = bme680.temperature
    temp = "null" if temp is None else round(temp,2)
    humid = bme680.humidity
    humid = "null" if humid is None else round(humid,2)
    press = bme680.pressure
    press = "null" if press is None else round(press,2)
    voc = bme680.gas
    voc = "null" if voc is None else round(voc,2)
    lux = tsl2561.lux
    lux = "null" if lux is None else round(lux,2)
    framecounter = framecounter+1
    
    print("Measurements: ",temp, humid, press, voc, lux, percentage)
    try:
        x = requests.post(URL, data={"device_ID":mac_address, "version": code_version, "temperature":temp, "humidity":humid, "pressure": press, "voc": voc, "illumination": lux, "dust": percentage, "counter": framecounter})
        wlan_check_flag = False
        print(x.text)
    except requests.exceptions.ConnectionError as err:
        print ("request failed:", err)
        wlan_check()

schedule.every(5).minutes.do(read_sensors)
schedule.every().day.at("02:00").do(take_picture)
schedule.every().day.at("04:00").do(take_picture)

print("mumo logger code started! (device ID: "+mac_address+")")
time.sleep(60) # wait a minute for wifi to start up.
read_sensors()
take_picture()
while True:
    schedule.run_pending()
    time.sleep(20)

cap.release()
GPIO.cleanup()

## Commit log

2020-11-28 update file_V2
    Mounting holes light sensor
    [NODE_Main_Housing_V2.stl]
2021-01-08 Gateway STL files
    [GATEWAY_Backcover.stl, GATEWAY_Main_Housing.stl]
2021-01-08 Extensions gateway
    [Bug_Trap.stl, Camera_Backcover.stl, Camera_Housing.stl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]
2021-01-08 This is the Arduino code for the node.
    Added some guide to what needs to be set-up as a summary. Refer to the instructables page for a more in depth guide.
2021-02-12 Cleanup and update in a lot of documentations
    Also added raw CAD files.
    [Bug_Trap.stl, Camera_Backcover.stl, Camera_Housing.stl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]
2021-02-16 Updates in readme and updated the STL of the Node
    [NODE_Main_Housing_V2.stl]
2021-04-24 Added endpoint logic for TTN.V3
    New integration data logic in TTN.V3 implemented.
    Worked on the open todo in the code to simplify the connections data to a single signal strength rssi value. This saves data in the database over longer durations.
    Added sample data from the TTN.V3.
2022-11-24 Call this device information using the Device_EUI instead of the NR id
    This allows to add privacy to the iframe pages.
2025-03-25 Add files via upload
    added experimental payload handler that manages newer payloads (multiple devices, battery levels,...)

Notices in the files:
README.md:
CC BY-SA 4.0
